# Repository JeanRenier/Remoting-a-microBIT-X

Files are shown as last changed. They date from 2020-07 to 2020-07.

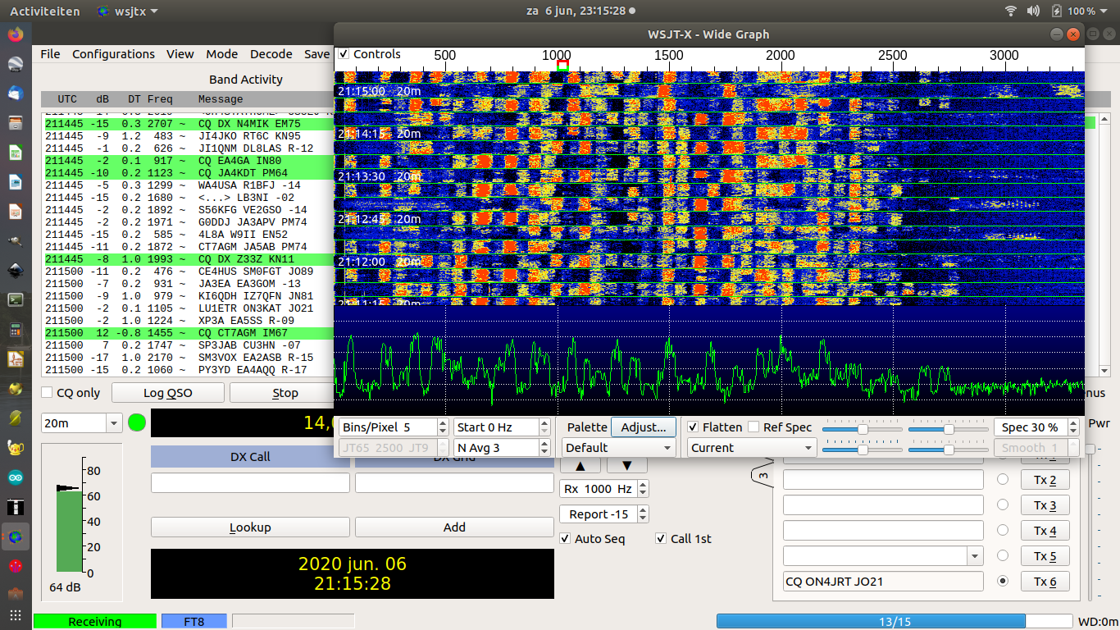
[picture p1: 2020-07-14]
pictures/WSJT-X_spectrum.png

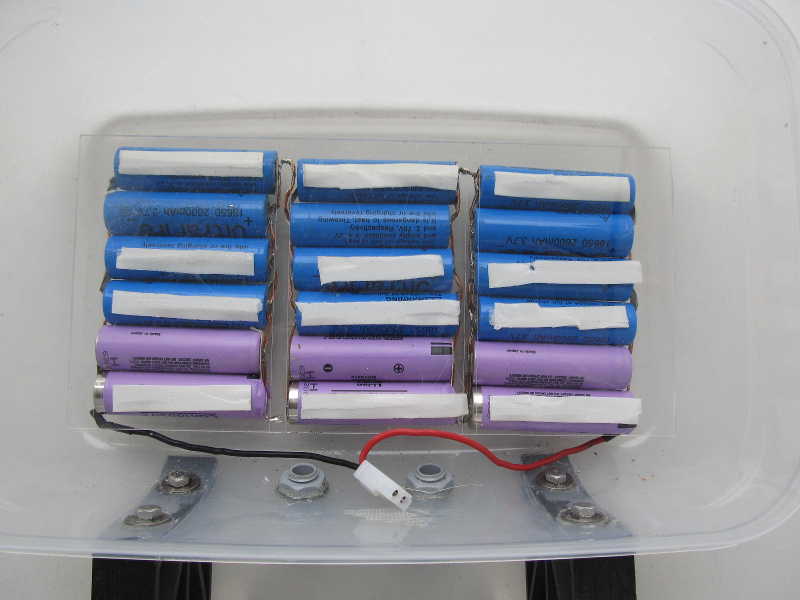
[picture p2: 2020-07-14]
pictures/remote_batteries.jpg

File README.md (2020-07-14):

**Introduction.**
 I became a licensed radio amateur when I retired some 10 years ago, my call is ON4JRT.
 Alas, moving to an apartment building a few years ago I lost the possibility to install a decent antenna. Even if I had the permission to install an antenna on the roof, the QRM generated by the building itself and the surrounding town would probably have made a clean reception almost impossible.
 A friend, who lives in the country side and to whom I am eternally grateful, came to my rescue and allowed me to install a remote transceiver and a modest antenna in his garden.

There are several remote transceiver projects described on the internet. Whilst they all are certainly more sophisticated and more performing than the rather simple system presented here, they are also much more demanding in resources (space, power, money, ...). I wanted a small stand alone system that would be self sustaining (save for an internet connection), not too conspicuous and not too expensive.
 Hence this project, which eventually was successful after a few trials. Its aim is to provide me with an remotely located transceiver for my own use, it is by no means a &quot;public&quot; transceiver available to other OM&#39;s.
 Like all engineering endeavor it consist of a series of choices and compromises, so don&#39;t shoot the pianist.

**The concept.**
 The remote transceiver system consists of several parts: A transceiver (obviously), a HF antenna, a battery, a small solar panel, a controller with a WiFi transceiver and a controller for the solar panel. Except for the HF antenna and the solar panel everything is enclosed in a small plastic housing of about 5 liter in volume.
 The remote transceiver communicates (i.e. the bidirectional data flows for sound, CAT and control) over the internet with a home device. This home device contains a simple user interface allowing some control over the remote device. Sound input and output is also available on this home device, as is a CAT interface. If I were a better PC/Posix software programmer I would probably gotten rid of the home device. Having the home device as a physical thing eases however the development (at least for me) while not adding too much to the cost.

**The transceiver.**
 After some search, I came across the µBIT-X (&quot;[https://www.hfsignals.com/index.php/ubitx/](https://www.hfsignals.com/index.php/ubitx/)&quot;) sold as a semi assembled kit developed by Ashhar Farhan (VU2ESE), now in its 6th version (I got the previous version for this project). It is a simple but rather well designed multi band HF QRP transceiver based on a double super architecture and bidirectional amplifiers (it uses almost all the building blocks for reception as well as for transmission). It is well documented, has a large fan club and most of the suggested improvements are officially endorsed.
 Coming out of the box, it needs to be calibrated and tuned (a bit). Apart from the CAT baud rate I didn&#39;t feel the need to modify anything. Obviously I didn&#39;t install the LCD or the rotary encoder (since nobody would look/touch at it), all control is performed via the CAT connection over the internet from the home device, and even then, very little of the CAT commands are really used.

**The µBIT-X controller, hardware.**

Beginning with the power supply: a DC/DC controller reduces the battery voltage to 4V, from there three linear regulators make the necessary 3.3V digital, 3.3V analog and 1.8V respectively.

An ESP32-WROOM module is the core of the controller, this awesome microprocessor includes the WiFi transceiver, performs all relevant IP chores and runs all the application software.
 It then interfaces a WM8731 codec by a I2Sbus for the digital sound and a I2Cbus for its control. This codec is a straight forward 16bit stereo ADC and DAC combination, it is programmed in this case for a sampling rate of 8kHz, yielding a sound bandwidth of 3400Hz, its dynamic range exceeds 90dB. The analog sound input and output from the codec goes through a set of isolating 600 Ohm 1:1 audio transformers and trimpots to the µBIT-X sound stages.
 The first UART of the ESP32 is exclusively used for programming and debugging.

The second UART interfaces the CAT of the µBIT-X including a PTT line. This interface is isolated with a set of optocouplers, limiting the baud rate to 4800. Note that the RD and TD lines of this interface actually bypass the USB-UART chip on the Arduino Nano board of the µBIT-X, luckily a series resistor was placed in the RD line of this Arduino Nano, hence no track cutting was nescessary.
 The third UART interfaces the Solar Controller board, it is also fit with optocouplers.
 At last the board is equipped with a PMOS switch capable of more than 2A to power the µBIT-X itself when required.

An additional small board comprising a simple tandem match type VSWR bridge is mounted directly on the antenna input/output of the µBIT-X. The detected forward and reflected signals are fed into the ADC inputs of the ESP32. With the help of some math and calibration, it gives a rather good indication of the HF power and VSWR during transmit.

**The µBIT-X controller, software.**

The software was build on the Arduino IDE (version 1.8.12) with the ESP32 plug in and libraries (version 1.0.4). It took several months of writing and careful testing, having the home device nearby was a great help.
 The software was not especially designed to be universal or portable. The several parameters like the IP addresses, URL&#39;s, etc. are &quot;hard coded&quot; in the software, no attempt was made for now to store them in a file structure or other form of non volatile memory. Hence there is no way to change them without recompiling the entire software.
 The software includes the interesting possibility of being updated &quot;over the air&quot;, i.e. via the WiFi as per the method recommended by Espressif. This was tested but not yet used, an additional port forwarding on the remote router is needed tor this.

The setup part of the software starts with the initialization of the several internal and external peripherals. After that a WiFi connection with one of the friendly WiFi AP&#39;s is established, that done the µBIT-X Controller will synchronizes with an NTP server, checking in at a DDNS server and send a short e-mail as a sign of live. Once the setup is done two endless loops will take care of business until powered off.
 One of the loops is dedicated to the audio interface, seeing to it that the digital sound samples flow in and out the codec through the I2Sbus at a constant rate of 8kHz.
 The other loop will handle the incoming and outgoing UDP packets. Outgoing packets are sent only when incoming UDP packets are present, i.e. only during a connection between the µBIT-X controller and the home device.

The data in each packet is split into three separate flows, the biggest one being the sound, a smaller one for the CAT going directly to/from the µBIT-X and the last one for the housekeeping of the µBIT-X Controller itself and the Solar Controller.

During a connection there is a UDP flow of 25 packets per second in each direction. Each packet has 660 bytes is build as follows:
 - bytes 0...639 : 320 16bit sound samples, 8000 samples/s

- byte 640...641 : packet count and control byte, including the PTT bit

- byte 642...646 : CAT bytes, max 5 to/from the µBIT-X

- byte 647...659 : CTL bytes, max 13 to/from the Solar Controller
 The sound samples of the incoming packets are stored in a circular buffer of 1s. Currently there is no provision made to cope with lost packets, if the circular buffer runs out, silence is send to the codec until its filled again for at least a quarter. Packet loss has not been a problem so far, typically no more than one packet per thousand gets lost.
 Likewise, differential drift of the sample clock, the 8kHz sampling rates at send and receive sides are not exactly equal, is simply ignored, though I may change this in future.

A few words about the IP addressing. In normal circumstances both the home device and µBIT-X Controller are connected to their respective WiFI AP&#39;s that are typically part of a modem router devices provided by Internet Access operators. The IP addresses of these devices are variable over time as the operators see fit. Hence the use of a DDNS server, the free service &quot;www.duckdns.org&quot; was chosen here. Both sides of the link are then known by their URL&#39;s i.e. &quot;remote\_name.duckdns.org&quot; and &quot;home\_name.duckdns.org&quot; respectively.
 That is one problem solved, still the packets need to pass the modem routers and be directed to the devices. This is done by setting a port forwarding for the appropriate port number in the modem router at both sides.
 Most modem routers have the tendency to assign a new IP address to the devices each time they connect. In order to avoid that, fixed IP addresses are organized for each device, hence the port forwarding can be set once and for all. The fixed IP addresses should carefully be chosen in order not to disturb the other IP stations on the local area (i.e. choosing one outside of the DHCP range of the modem).
 A more elegant solution to avoid the fixed IP addresses and the port forwarding settings in the modem routers would be the use of the UPnP method. There are good libraries for this method, e.g. &quot;[https://github.com/ofekp/TinyUPnP](https://github.com/ofekp/TinyUPnP)&quot;, with which I played a bit. It probably works but I was not able to test it due to some issues with my own modem router, so I stick with the port forwarding and fixed IP addresses for now.

**The solar panel controller.**
 The µBIT-X controller board (see further) takes about 38mA during normal operation (the µBIT-X itself being turned off), this was deemed too much to have it continuously running. Hence a scheme was preferred where the remote transceiver would become available through the internet for a few hours everyday at some predetermined time, e.g. from 8 o&#39;clock in the evening till midnight. This scheme works for me, though it may not be the case for everybody.

For this alarm clock/timer function a 24 hour real time clock was implemented in software. The power on time, the power off time and also the current time are settable remotely once a connection with the home device has been made.
 Besides of the above function the solar controller board is also supervising the charge of the battery. This function is kept extremely simple: when the battery voltage rises higher than 12.3V a PMOS switch is opened prohibiting the further charging of the battery from the solar panel. Likewise, if the battery voltage falls below 9.3V an other PMOS switch will cut the load (i.e. the rest of the system) in order to protect the battery from deep discharge damage. As the solar panel itself behaves very much like a current source and yields at most about 0.6A, no attempt is made to limit the charging current, it remains well below the maximum charging current of the Li-Ion battery.

This little board was designed some four years ago, it is built around the ATtiny84 chip and is furthermore connected via a serial port to the µBIT-X controller for housekeeping, such as the above mentioned timings, the battery voltage and the temperature inside the box. It takes a mere 3mA (continuously) from the battery.

**The battery.**
 Nothing very much is to be said about the battery, it is just an assembly of 18 Li-Ion cells of the 18650 format, 6 in parallel and 3 in series, yielding a nominal voltage of 11.1V and a capacity of 13Ah.
 Nothing is foreseen to perform load balancing, as is typical for Li-Ion batteries. After three &quot;campaigns&quot; in the field of 6 months each, no significant voltage drift was noted on the individual cell groups. This may be due to the rather gentle use of this battery, it is used mostly when nearly full (close to 12V), charged with no more than 0.6A (limited by the solar panel) and discharged with no more than 1.5A (µBIT-X transmitting) and the latter only during short periods.
 There is some concern about the temperature range of the the Li-Ion batteries: 0...40°C, which can easily be overreached during cold winters and hot summers. A thin Aluminum sheet is foreseen behind the south side of the housing to provide some shade for it.

**The housing.**
 A regular fridge/kitchen type PE box with a watertight lid of roughly 300\*200\*100mm (ca. 5 liter) was chosen as a housing for the entire remote system. An unorthodox choice, but there were never any problems with rain or weather during the accumulated 18 plus months of outdoor live so far.
 The box is traversed by two cables, one for the HF antenna (RG 58 coax) and one for the solar panel (round flexible twin electricity cable), both foreseen with pressure glands.
 Two &quot;feet&quot; are furthermore foreseen to enable the box to stand upright with its 200mm side vertical.
 The rear part of the box is reserved for the battery, the front part for the WiFi antenna (a double biquad), the in between space is filled with the µBIT-X, the µBIT-X controller and the solar controller. It was a bit of a shoe horn exercise, but nobody did complain...
 A few pouches of silica gel drying agent were inserted before the final closure of the lid.

**The solar panel.**
 The solar panel looks a bit like a picture frame, a slim Aluminum frame holds two sheets of glass between which 35 poly-crystalline photo voltaic cells are mounted in series. Its dimension is 330\*290mm. It is rated 10W by the manufacturer, if exposed perpendicular to the sun during a clear day it would yield about 17.5V (open circuit) and 0.6A (short circuit). It is installed in the garden more or less in an open space, near to the remote transceiver box, facing south and tilted at 45°.
 Theoretically, considering the statistics for my part of the world, it would yield 3.5Ah on an average summer day and 0.7Ah on an average winter day. Plenty to play with, at least during summer.

**The antenna.**
 Discretion is the keyword here, a simple 20m band wire dipole was installed horizontally between the trees in the garden. For practical reasons the resonant feed line design was chosen here, the height above the ground is about 3.5m. Alas, too low to make it a good DX antenna, but then it was that or nothing. The antenna is entirily made of RG58 cable, a nylon rope runs along with it for improved strength.
 The antenna impedance was measured and a small fixed LC circuit was installed in the remote transceiver box as an antenna tuner of sorts to ensure that the VSWR remains below 1.5.
 It was noted that the VSWR varies from 1.2 to 1.5 depending the weather.

**The home device, hardware.**
 The hardware of the little home device is very similar as that of the µBIT-X Controller. The sound is connected to the audio input/output of a PC with a 3.5mm audio jack. The incoming sound is also diverted to a small (30mm) loudspeaker to monitor the received signal.
 Note that the sound levels are kept intentionally high (i.e. around 1Veff), this in order to maximize the S/N ratio. The sound input/output towards the PC must hence be set accordingly (maximum for the output and almost nil for the input).
 The second UART is led through a UART-USB chip and is used for the CAT. The USB connection is also used for powering the home device. Further peripherals are a small OLED display (128\*64 pixels) connected to the I2Cbus (to monitor some vital parameters of the remote), a rotary encoder (to change the frequency), a potentiometer (speaker volume) and a toggle switch (to start/stop the connection with the remote).

**The home device, software.**
 The software of the little home device is also very similar to that of the µBIT-X Controller. No NTP synchronization or e-mail sending, instead the OLED display is configured during setup.
 During looping, the sending of packets is controlled by the toggle switch. Control and CAT messages coming from the remote are parsed and put on the OLED display: current frequency and mode, HF power out, VSWR, received packet count (at both ends), RSSI of the WiFi link (at both ends), battery voltage and temperature inside the housing.

A few words about the handling of the CAT messages. By design the µBIT-X emulates (at least the meaningful part of) the CAT messages of the Yeasu FT817/FT857 transceiver. This works well when the µBIT-X is connected directly to a PC, I could however not make it work when connected to through the chain of devices and the internet, most probably a question of delay.
 The following scheme was then implemented: The home device emulates in itself the above transceivers, responding immediately to satisfy the application on the PC. If something is changed (in practice the frequency or the mode) the corresponding message is send over the internet to the remote µBIT-X controller and to the µBIT-X itself. Any response of the latter is returned over the internet to the user interface of the home device.
 This scheme works well with Fldigi, however not at all with WSJT-X for reasons I have yet to understand. As for the PTT, three methods are simply used in parallel: the DTR method, the CAT method and the VOX method (implemented in software).

**Construction notes.**
The PCB&#39;s were designed with KiCad (version 5.1.6) in the form of a two layer board with generous ground planes. Most of the components are SMD though still solderable by hand.
 The board assembled in one panel were manufactured by jlcpcb.com, they offer an excellent and fast service. Care was taken to get all the boards within an area of 100\*100mm, their more or less permanent prototype discount offer.
 Most of the components were purchased at &quot;www.tme.eu&quot; and &quot;[www.r](http://www.reichelt.com/)[eichelt.com](http://www.reichelt.com/)&quot;. The more exotic components (OLED display, audio transformers, ESP32-WROOM module, WM8731A, …) were purchased at &quot;[www.aliexpress.com](http://www.aliexpress.com/)&quot;, the stuff is on the road for about 6 weeks, but the price is unbeatable.

In order to load the software into the ESP32 with the Arduino IDE, a small UART-USB module should be connected to the first UART (debug, only the RD, TD and GND lines), the boot strap should be shorted and the reset button should be pressed.
 The Solar Controlled was designed several years earlier, its software was made with AVR Studio 4. Alas, there is no Arduino IDE support for the ATtiny84.
 Finally, the housing of the home device was 3D-printed (a little box of 100\*50\*30mm), it was designed with OpenScad.

**Performance of the system as a whole.**

I am active only on the 20m band for now, the antenna being strictly monoband, and then mostly in the popular FT8 mode. With the 6...7W of output power it seems that I suffer some 10...15dB disadvantage versus other stations (difference of their S/N report versus my S/N report). This is probably more an issue of the QRP nature of the µBIT-X than the fact it is connected via the internet.
 The additional time delay due to digitization and buffering of the sound does not seem to have a significant effect, it is about 0.7s.

An other concern is the lack of cooling in the rather hermetic non metallic housing. When busy for one hour atempting QSO&#39;s in FT8, the temperature inside the housing will rise by typically 5°C. Not too bad, but then it says little about the temperature of the power FET&#39;s of the PA. Initial tests however indicated that their rather small radiators didn&#39;t became too hot even after several minutes of transmitting.

Battery drain of the remote part:
 - Solar Controller: 3mA (continuous)
 - µBIT-X Controller: 38mA (when awake)

- µBIT-X receiving: 175mA (when connected with the home device)
 - µBIT-X transmitting: 1125mA (when transmitting a single tone at 6W)

**Further improvements and other considerations.**
 Since the µBiT-X is multi band, as a further evolution of this project, I intend to have a multi band antenna (at least adding the 40m band) and some form of switchable/variable antenna tuner.

Some trick to capture the speed of rotation of the rotary encoder on the home device and to vary the frequency step accordingly would be useful. Now each step is strictly 100Hz, which is rather inconvenient. Making WSJT-X&#39;s CAT work with the home device would also be nice.
 Currently there is no provision made as for internet security, i.o.w. anybody with the right format of UDP packets can access the remote device and use it (he/she has still to know the relevant URL of course). Some scheme with an encrypted signature (e.g. HMAC style) inside each packet authenticating the home device would be an improvement.
 Though the current design is intended for the use with digimodes, it can easily be adapted for voice operations. Adding a microphone amplifier and a PTT switch input would then be required.

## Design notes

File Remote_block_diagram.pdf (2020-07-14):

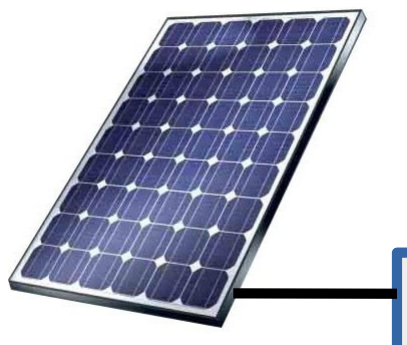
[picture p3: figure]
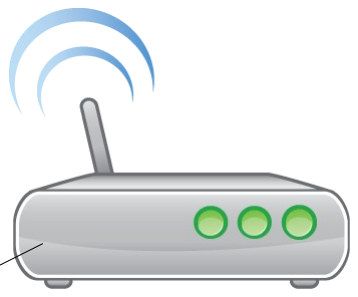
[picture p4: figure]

Remote
unit

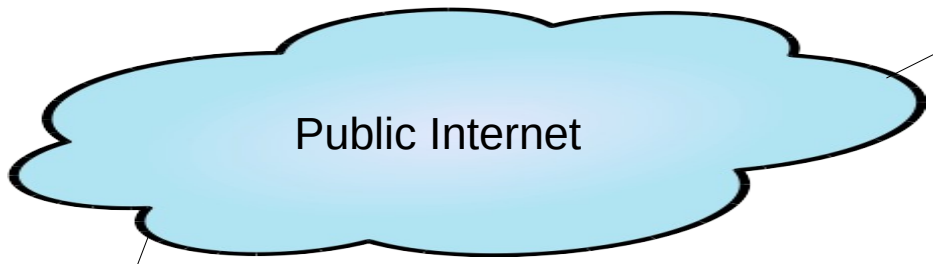
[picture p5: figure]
Public Internet
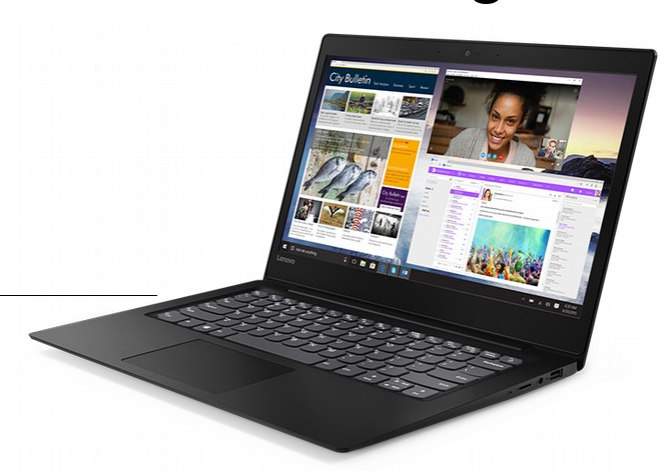
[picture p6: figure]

Local
unit

Remote WiFi LAN

Local WiFi LAN

10Wp Solar panel

20m RFD antenna

PC with FLdigi, WSJT, ...

## λ Remote unit (block diagram)

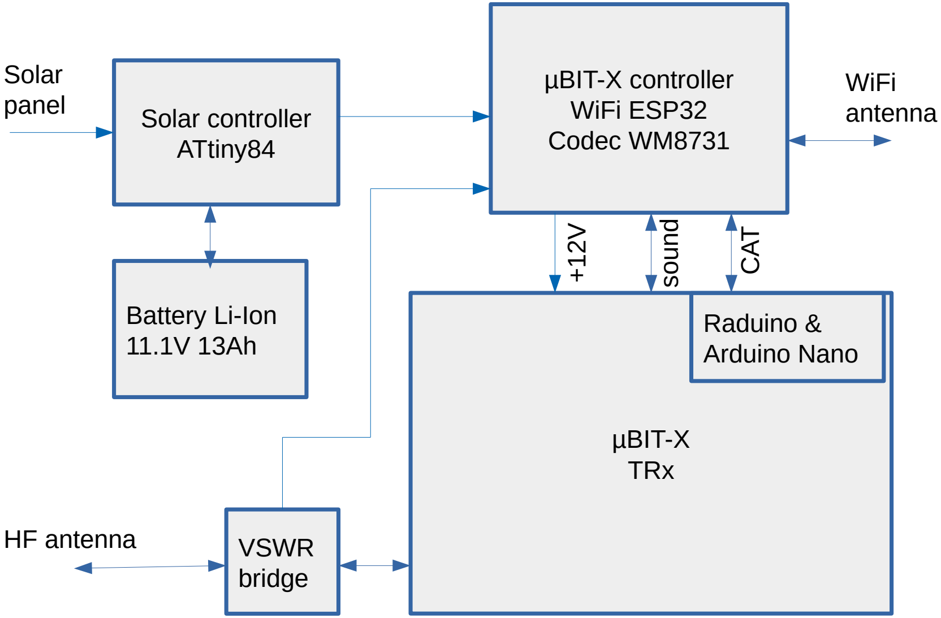
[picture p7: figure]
Solar controller ATtiny84; µBIT-X controller WiFi ESP32 Codec WM8731; Battery Li-Ion 11.1V 13Ah; µBIT-X TRx; VSWR bridge; Solar panel; WiFi antenna; HF antenna; Raduino & Arduino Nano

## λ Local unit (block diagram)

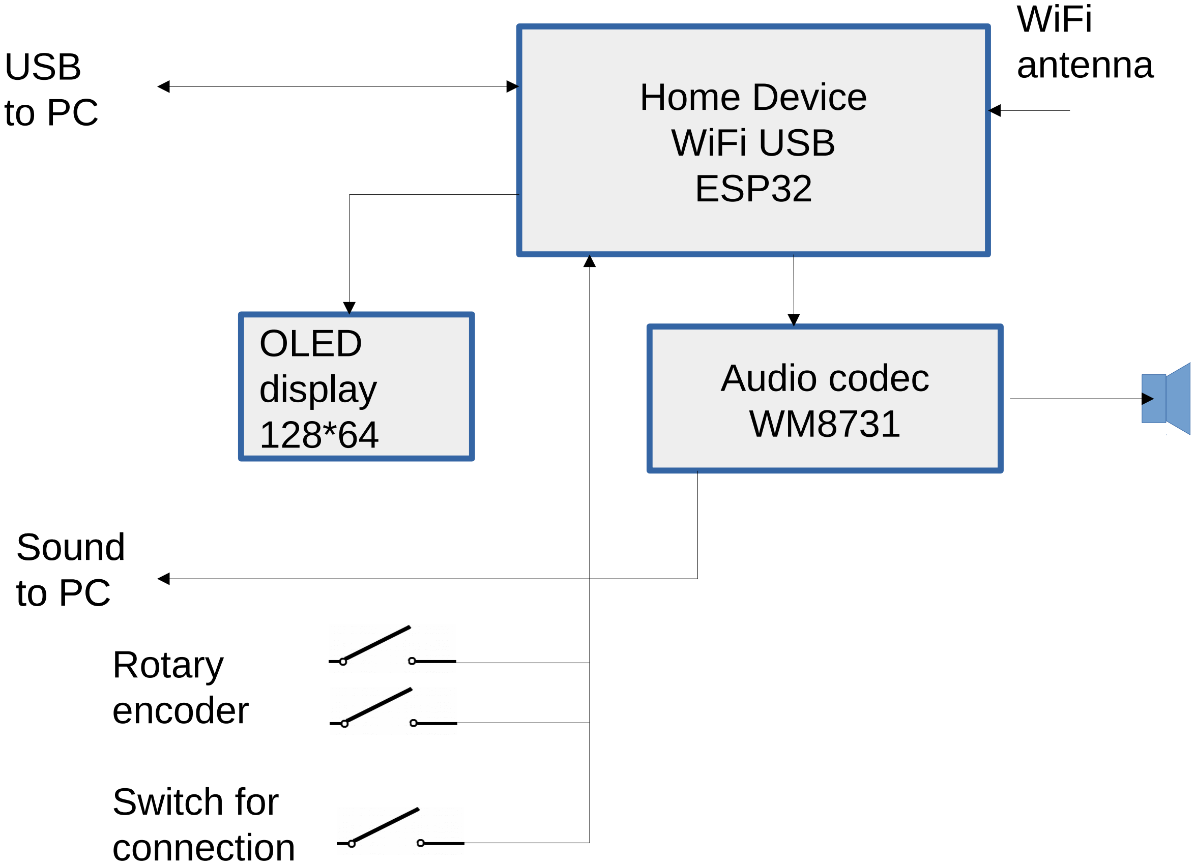
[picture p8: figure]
Home Device WiFi USB ESP32; Audio codec WM8731; WiFi antenna; OLED display 128*64; Sound to PC; USB to PC; Rotary encoder; Switch for connection

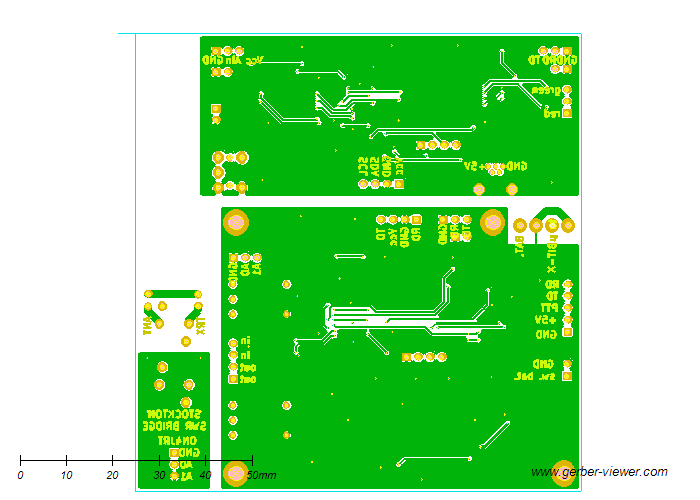
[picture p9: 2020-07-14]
hardware/remote3_layout_bot.png

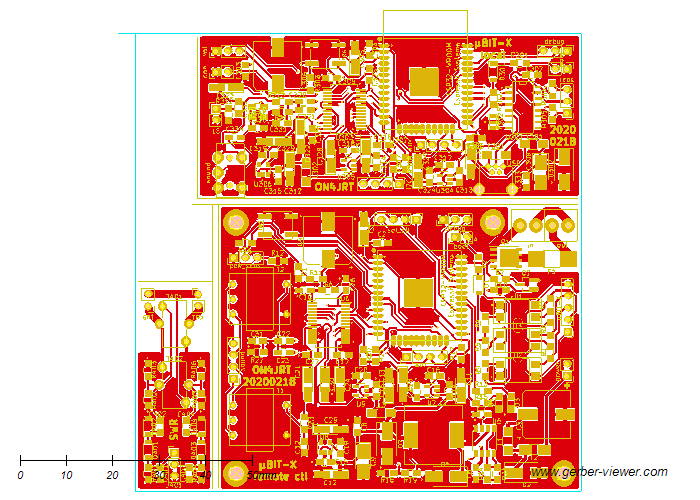
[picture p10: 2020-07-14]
hardware/remote3_layout_top.png

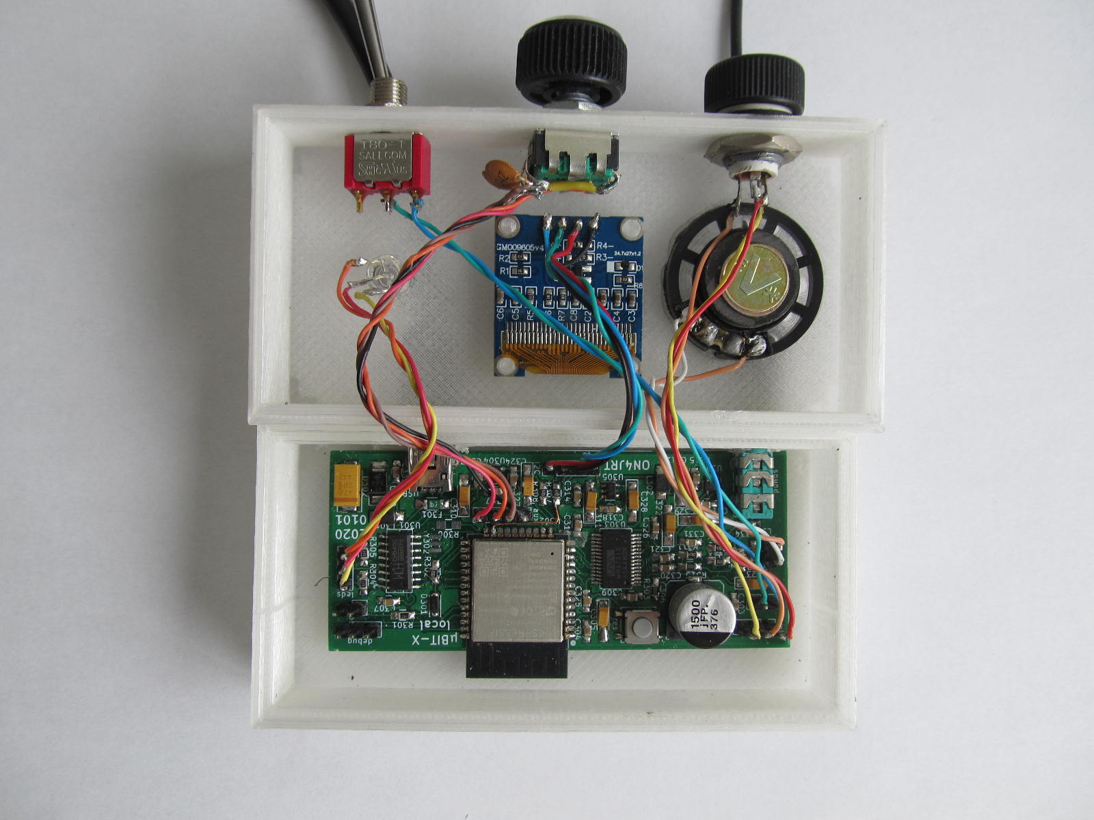
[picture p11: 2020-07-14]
pictures/home_interns.jpg

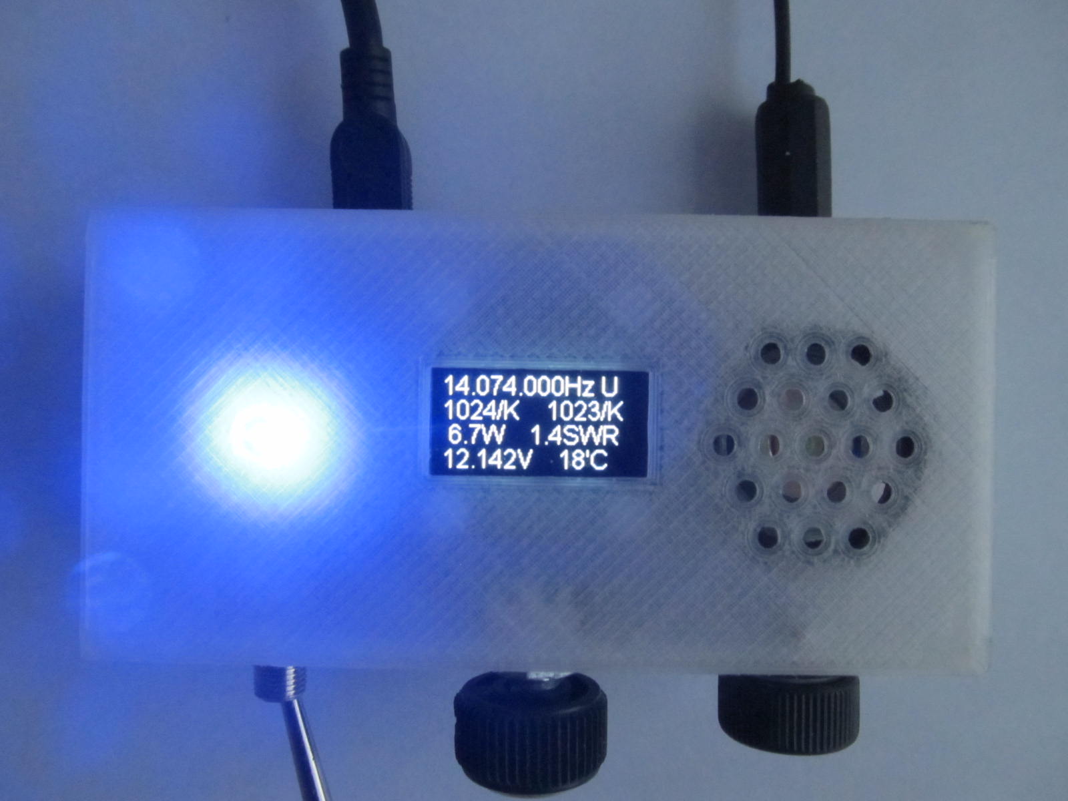
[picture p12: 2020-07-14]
pictures/home_transmitting.jpg

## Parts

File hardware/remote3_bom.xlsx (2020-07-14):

Id | Designator | Package | Quantity | Designation | Supplier and ref
Semiconductors
1 | U302 | ESP32-WROOM | 1 | ESP32-WROOM 32D with PCB antenna | AliExpress
2 | U4 | ESP32-WROOM | 1 | ESP32-WROOM 32U with IPEX connector | AliExpress
3 | U1,U2,U3 | DIP-4_W7.62mm_SMDSocket_SmallPads | 3 | SFH1690AT
4 | U5 | SOIC-8_3.9x4.9mm_Pitch1.27mm | 1 | MC34063
5 | U6,U303 | SSOP-28_5.3x10.2mm_Pitch0.65mm | 2 | WM8731 | AliExpress
6 | U7,U9,U304,U306 | SOT-23-5 | 4 | tc1185-3.3V
7 | U8,U305 | SOT-23-5 | 2 | tc1185-1.8V
8 | U301 | SO-16-N | 1 | CH340G | AliExpress
9 | Q1 | PowerPAK_SO-8_Single | 1 | AO4407A
10 | Q2 | SOT-23_Handsoldering | 1 | BSS138
11 | D3 | LED_0805_HandSoldering | 1 | green
12 | D4 | LED_0805_HandSoldering | 1 | red
13 | D1,D301 | D_SOD-123 | 2 | 1N4148
14 | D2 | D_SMB_Handsoldering | 1 | 15V transil
15 | D7,D302 | D_SMB_Handsoldering | 2 | 5.1V transil
16 | D5,D401,D402,D403,D404 | D_SOD-123 | 5 | BAT85
Inductors
17 | L1,L3,L301,L302 | L_1206_HandSoldering | 4 | 10u
18 | L2 | L_12x12mm_h8mm | 1 | 100u
19 | T401,T402 | L_Toroid_Vertical_L10.0mm_W5.0mm_P5.08mm | 2 | FT-37-43
Capacitors
20 | C7,C18,C19,C20,C31,C32,C317,C318,C319,C330,C331,C332 | C_0805_HandSoldering | 12 | 470p
21 | C1,C303 | C_0805_HandSoldering | 2 | 10n
22 | C2,C6,C8,C10,C14,C15,C16,C17,C22,C23,C25,C26,C27,C304,C307,C309,C313,C314,C315,C316,C320,C321,C324,C325,C326,C401,C402,C333,C334,C403,C404 | C_0805_HandSoldering | 31 | 100n
23 | C3,C305 | CP_Tantalum_Case-A_EIA-3216-18_Hand | 2 | 1.5u
24 | C11,C12,C13,C21,C24,C28,C29,C30,C310,C311,C312,C322,C327,C328,C329 | CP_Tantalum_Case-A_EIA-3216-18_Hand | 15 | 10u
25 | C9,C308,C323 | CP_Tantalum_Case-B_EIA-3528-21_Hand | 3 | 100u
26 | C5 | CP_Elec_10x10 | 1 | 470u, 16V
27 | C4,C306 | CP_Elec_10x10 | 2 | 1500u, 6V
Resistors
28 | R14,R24 | R_0805_HandSoldering | 2 | 1
29 | R312 | R_0805_HandSoldering | 1 | 10
30 | R23 | R_0805_HandSoldering | 1 | 33
31 | R402,R403,R405,R406 | R_0805_HandSoldering | 4 | 100
32 | R2,R5,R9,R13,R15,R301,R304,R305 | R_0805_HandSoldering | 8 | 330
33 | R3 | R_0805_HandSoldering | 1 | 680
34 | R4 | R_0805_HandSoldering | 1 | 3.3k
35 | R1,R8,R20,R21,R307,R308,R309,R313 | R_0805_HandSoldering | 8 | 4.7k
36 | R6,R7,R10,R11,R17,R18,R302,R303,R306,R401,R404 | R_0805_HandSoldering | 11 | 10k
37 | R19 | R_0805_HandSoldering | 1 | 22k
38 | R12,R16 | R_0805_HandSoldering | 2 | 100k
39 | R22,R310,R311 | R_0805_HandSoldering | 3 | 51k
Other
40 | Y302 | Resonator_SMD-3pin_7.2x3.0mm | 1 | 12MHz | AliExpress
41 | T2,T1 | Transformer 13.5*13.4*9.1mm | 2 | 1:1, 600Ohm, 1.6H, | AliExpress
42 | push button | SW_SPST_EVPBF | 2 | reset
43 | F2,F301 | R_1206_HandSoldering | 2 | 0.35A
44 | F1 | R_1812_HandSoldering | 1 | 2.6A
Connectors
45 | USB_B_mini | USB mini_B THT, angled | 1 | JST: UB-M5BR-DM14-4D
46 | sound | PJ320E_3.5mm_Jack | 1 | salvage
47 | in,out | TerminalBlock_bornier-2_P5.08mm | 2
48 | in | TerminalBlock_bornier-2_P5.08mm | 1
49 | diverse | Pin_Header_Straight_1x10_Pitch2.54mm | 5 | breakable
Off board
50 | potentiometer | 6mm shaft, hole mount, 10k linear | 1 | plus dito knob
51 | rotary encoder | 6mm shaft, incl. push switch | 1 | plus dito knob | AliExpress
52 | loadspeaker | Miniature: 30mm diam., 32 Ohm | 1 |  | AliExpress
53 | OLED display | 0,96” diagonal, 128*64 pixels, white/blue, IC2 interface | 1 |  | AliExpress
54 | toggle switch | 6mm shaft, hole mount, SPST | 1
55 | leds | 5mm led, common anode | 1 | bicolor led (red/green)
56 | diverse | Pin_Header_Female Straight_1x10_Pitch2.54mm | 5

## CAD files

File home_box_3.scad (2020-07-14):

// box for remote HF mk3 home device

module grid() {
    for (i = [0:4]) {
        translate([i*5,0,0])cylinder(d=3, h= 4, $fn=90);
    }
    for (i = [0:3]) {
        translate([2.5 + (i*5),5,0])cylinder(d=3, h= 4, $fn=90);
        translate([2.5 + (i*5),-5,0])cylinder(d=3, h= 4, $fn=90);
    }
    for (i = [0:2]) {
        translate([5 + (i*5),10,0])cylinder(d=3, h= 4, $fn=90);
        translate([5 + (i*5),-10,0])cylinder(d=3, h= 4, $fn=90);
    }
}
// bottom part
    translate([0,55,0])difference() {
        union() {
        // bottom
        translate([-50,-25,0])cube([100,50,1.5]);
        // walls & rims
        translate([-50,-25,0])cube([3,50,15]);
        translate([-50,-25,15])cube([1.4,50,2.5]);
        translate([47,-25,0])cube([3,50,15]);
        translate([48.6,-25,15])cube([1.4,50,2.5]);
        translate([-50,-25,0])cube([100,3,15]);
        translate([-50,-25,15])cube([100,1.4,2.5]);
        translate([-50,22,0])cube([100,3,15]);
        translate([-50,23.6,15])cube([100,1.4,2.5]);
    }
      // usb
      translate([27,-26,4])cube([10,6,5]);
      // sound
      translate([-27,-21,7])rotate([90,0,0])cylinder(d=6, h=6, $fn=90);
}
     
// top part
difference () {
    union() {
      // bottom
      translate([-50,-25,0])cube([100,50,1.5]);
      // walls & rims
      translate([-50,-25,0])cube([3,50,15]);
      translate([-48.4,-23.4,15])cube([1.4,46.8,2.5]);
      translate([47,-25,0])cube([3,50,15]);
      translate([47,-23.4,15])cube([1.4,46.8,2.5]);
      translate([-50,-25,0])cube([100,3,15]);
      translate([-47,-23.4,15])cube([94,1.4,2.5]);
      translate([-50,22,0])cube([100,3,15]);
      translate([-47,22,15])cube([94,1.4,2.5]);
      // OLED display attachments
      translate([10,15,0])cylinder(d=2.6, h= 7.5, $fn=90);
      translate([-10,15,0])cylinder(d=2.6, h= 7.5, $fn=90);
      translate([10,-8,0])cylinder(d=2.6, h= 7.5, $fn=90);
      translate([-10,-8,0])cylinder(d=2.6, h= 7.5, $fn=90); 
      translate([10,15,0])cylinder(d=4.8, h= 4.5, $fn=90);
      translate([-10,15,0])cylinder(d=4.8, h= 4.5, $fn=90);
      translate([10,-8,0])cylinder(d=4.8, h= 4.5, $fn=90);
      translate([-10,-8,0])cylinder(d=4.8, h= 4.5, $fn=90);  
    }    
     // OLED display
    translate([-12,-4,-1])cube([24,12,4]);      
    // loudspeaker
    translate([-40,0,-1])grid();
    // LED
    translate([30,0,-1])cylinder(d=5, h= 4, $fn=90);
    // connect swirch
    translate([30,-21,8.5])rotate([90,0,0])cylinder(d=6.2, h= 6, $fn=90);
    // connect switch
    translate([0,-21,8.5])rotate([90,0,0])cylinder(d=7, h= 6, $fn=90);  
    // volume potentiometer
    translate([-30,-21,8.5])rotate([90,0,0])cylinder(d=10.2, h= 6, $fn=90);
  }
 
  // adesion helpers (optional)
  translate([50,25,0])cylinder(d=8, h=1, $fn=60);
  translate([50,-25,0])cylinder(d=8, h=1, $fn=60);
  translate([-50,25,0])cylinder(d=8, h=1, $fn=60);
  translate([-50,-25,0])cylinder(d=8, h=1, $fn=60); 
  translate([0,55,0]) {
  translate([50,25,0])cylinder(d=8, h=1, $fn=60);
  translate([50,-25,0])cylinder(d=8, h=1, $fn=60);
  translate([-50,25,0])cylinder(d=8, h=1, $fn=60);
  translate([-50,-25,0])cylinder(d=8, h=1, $fn=60); } 

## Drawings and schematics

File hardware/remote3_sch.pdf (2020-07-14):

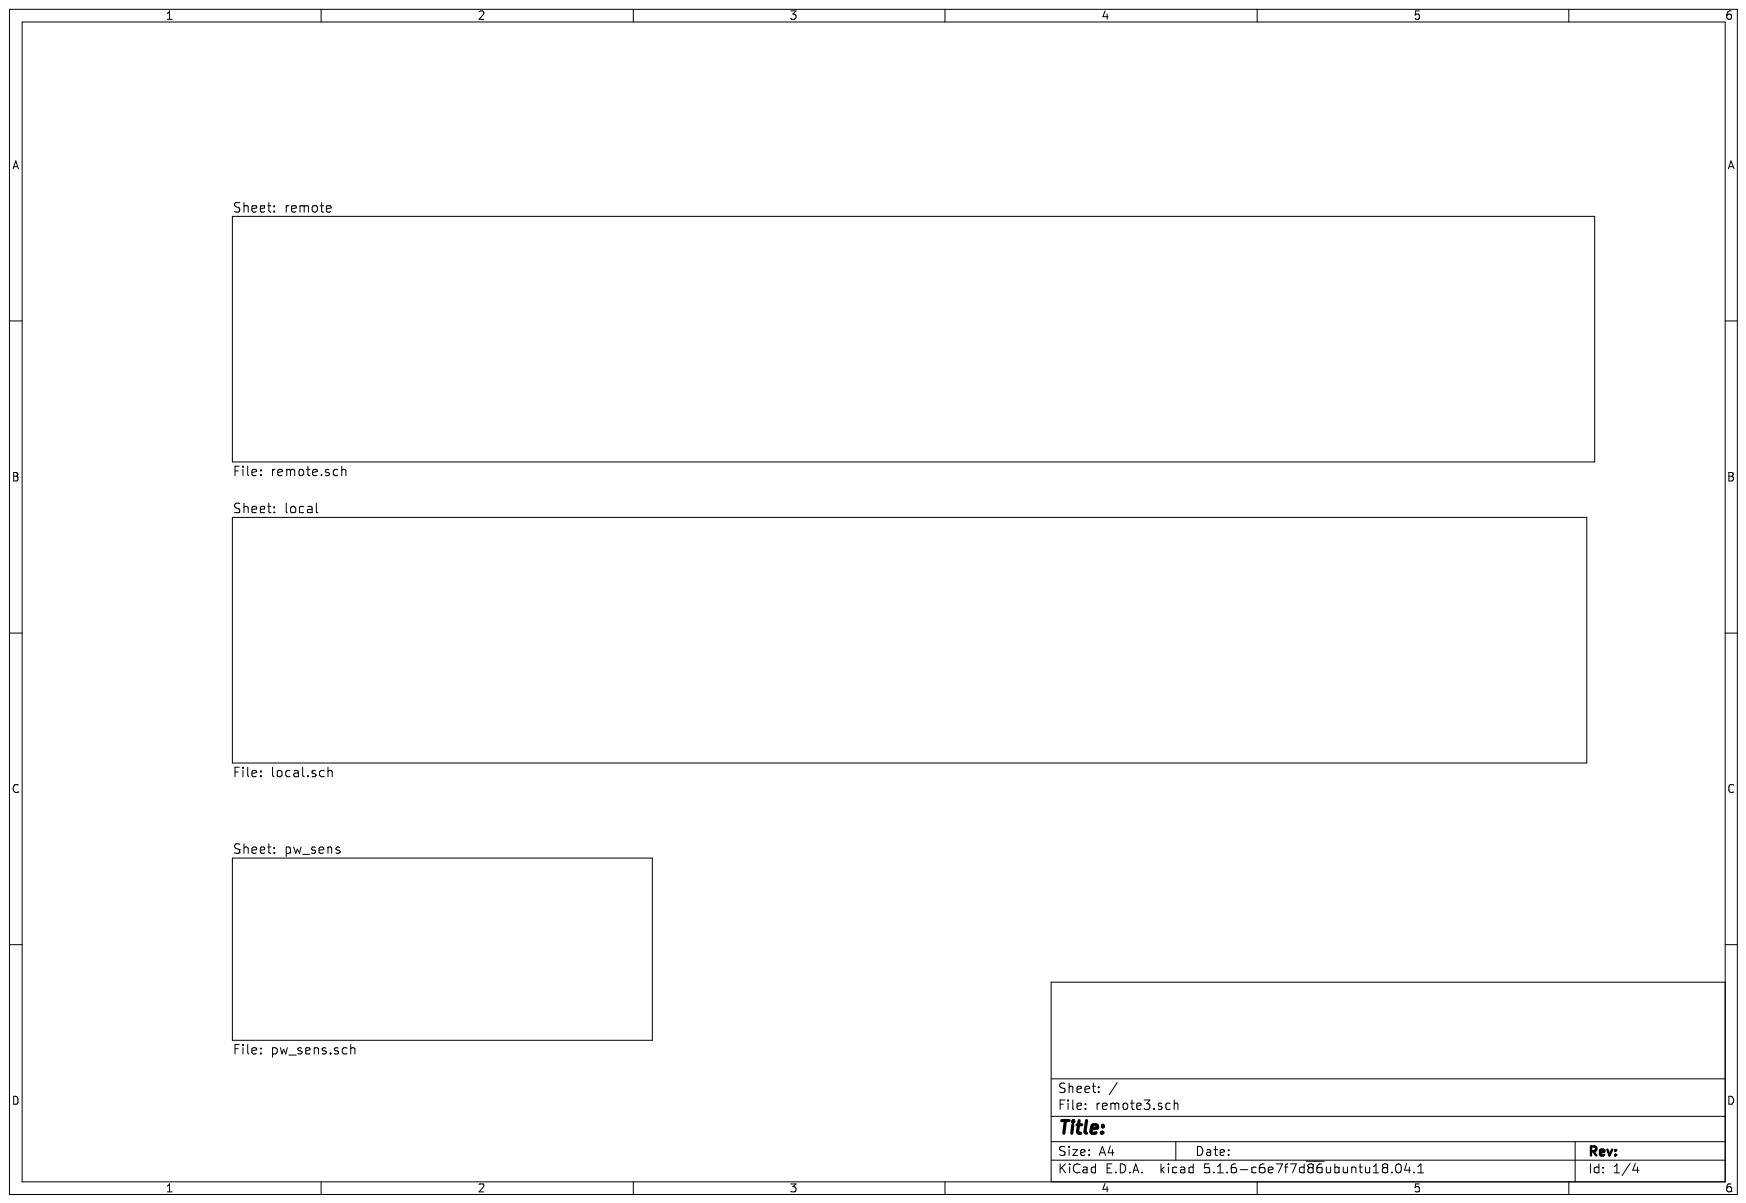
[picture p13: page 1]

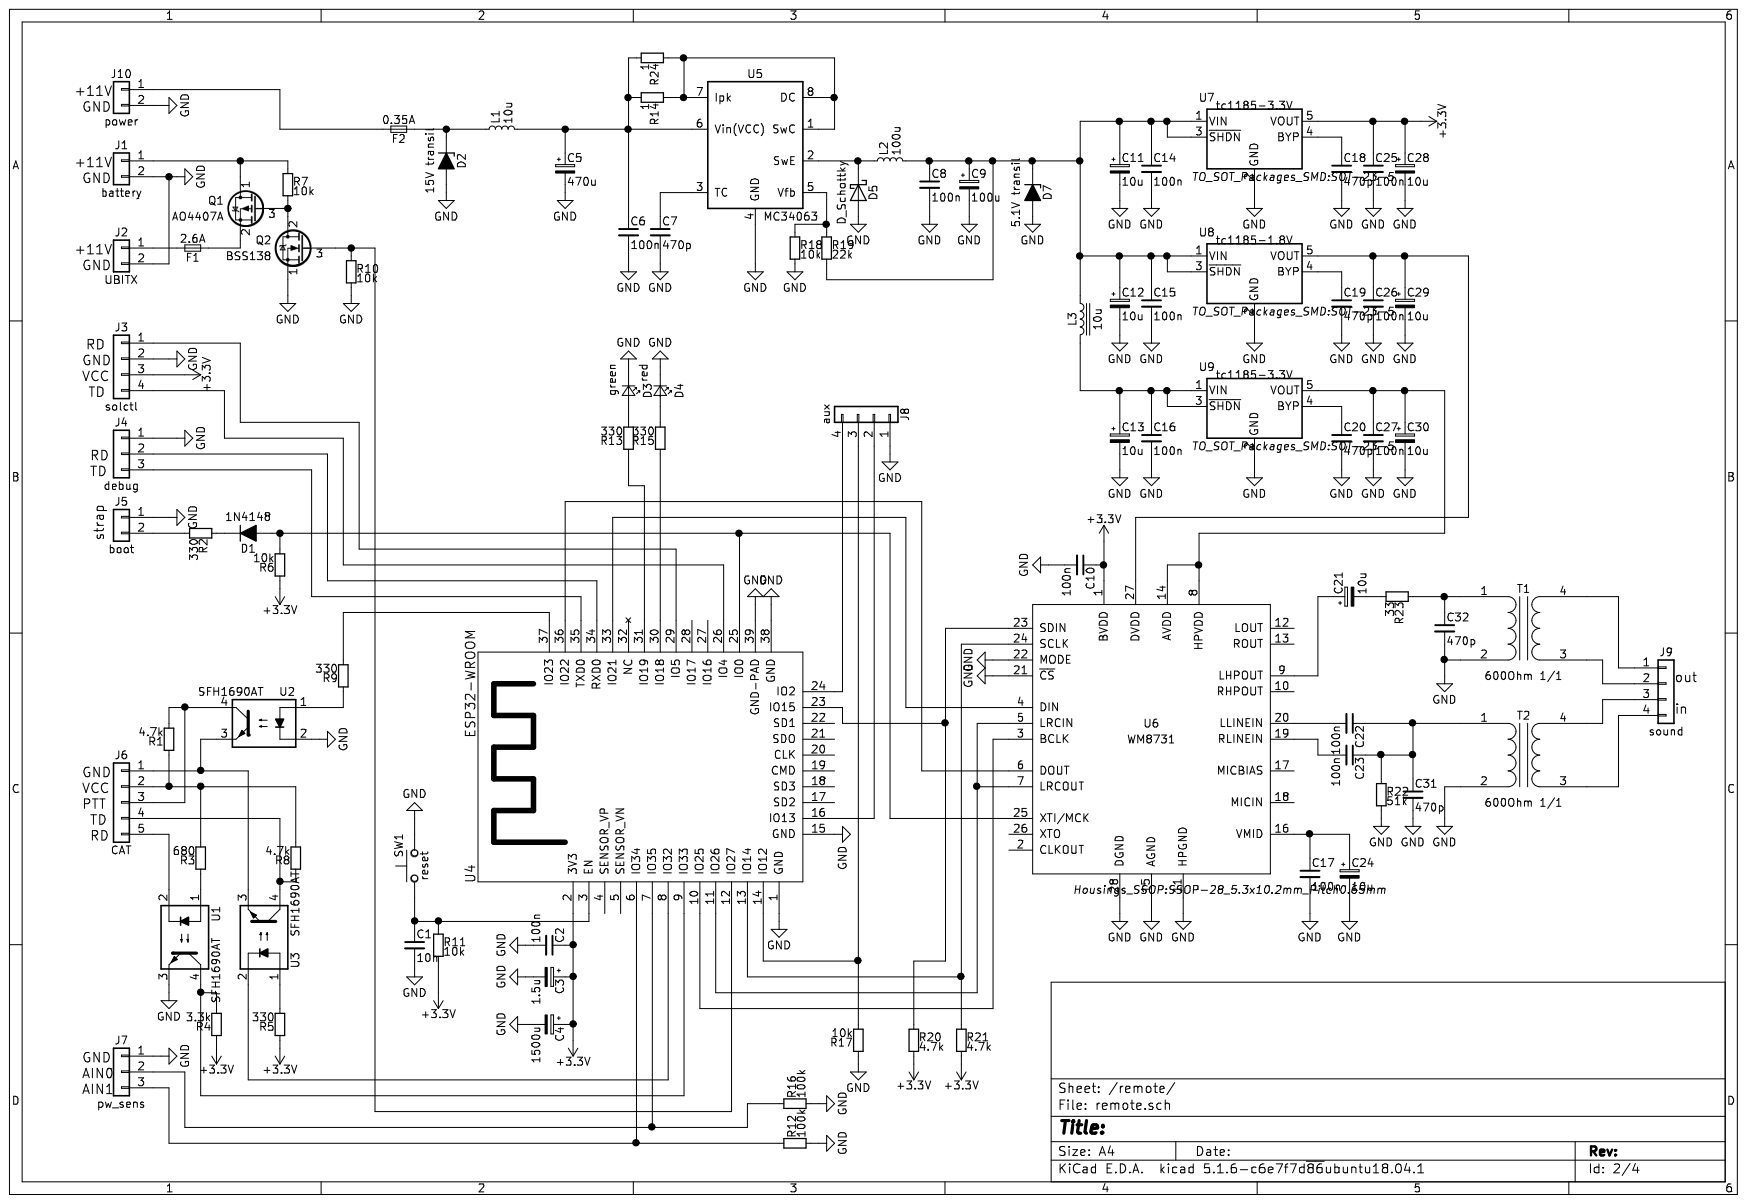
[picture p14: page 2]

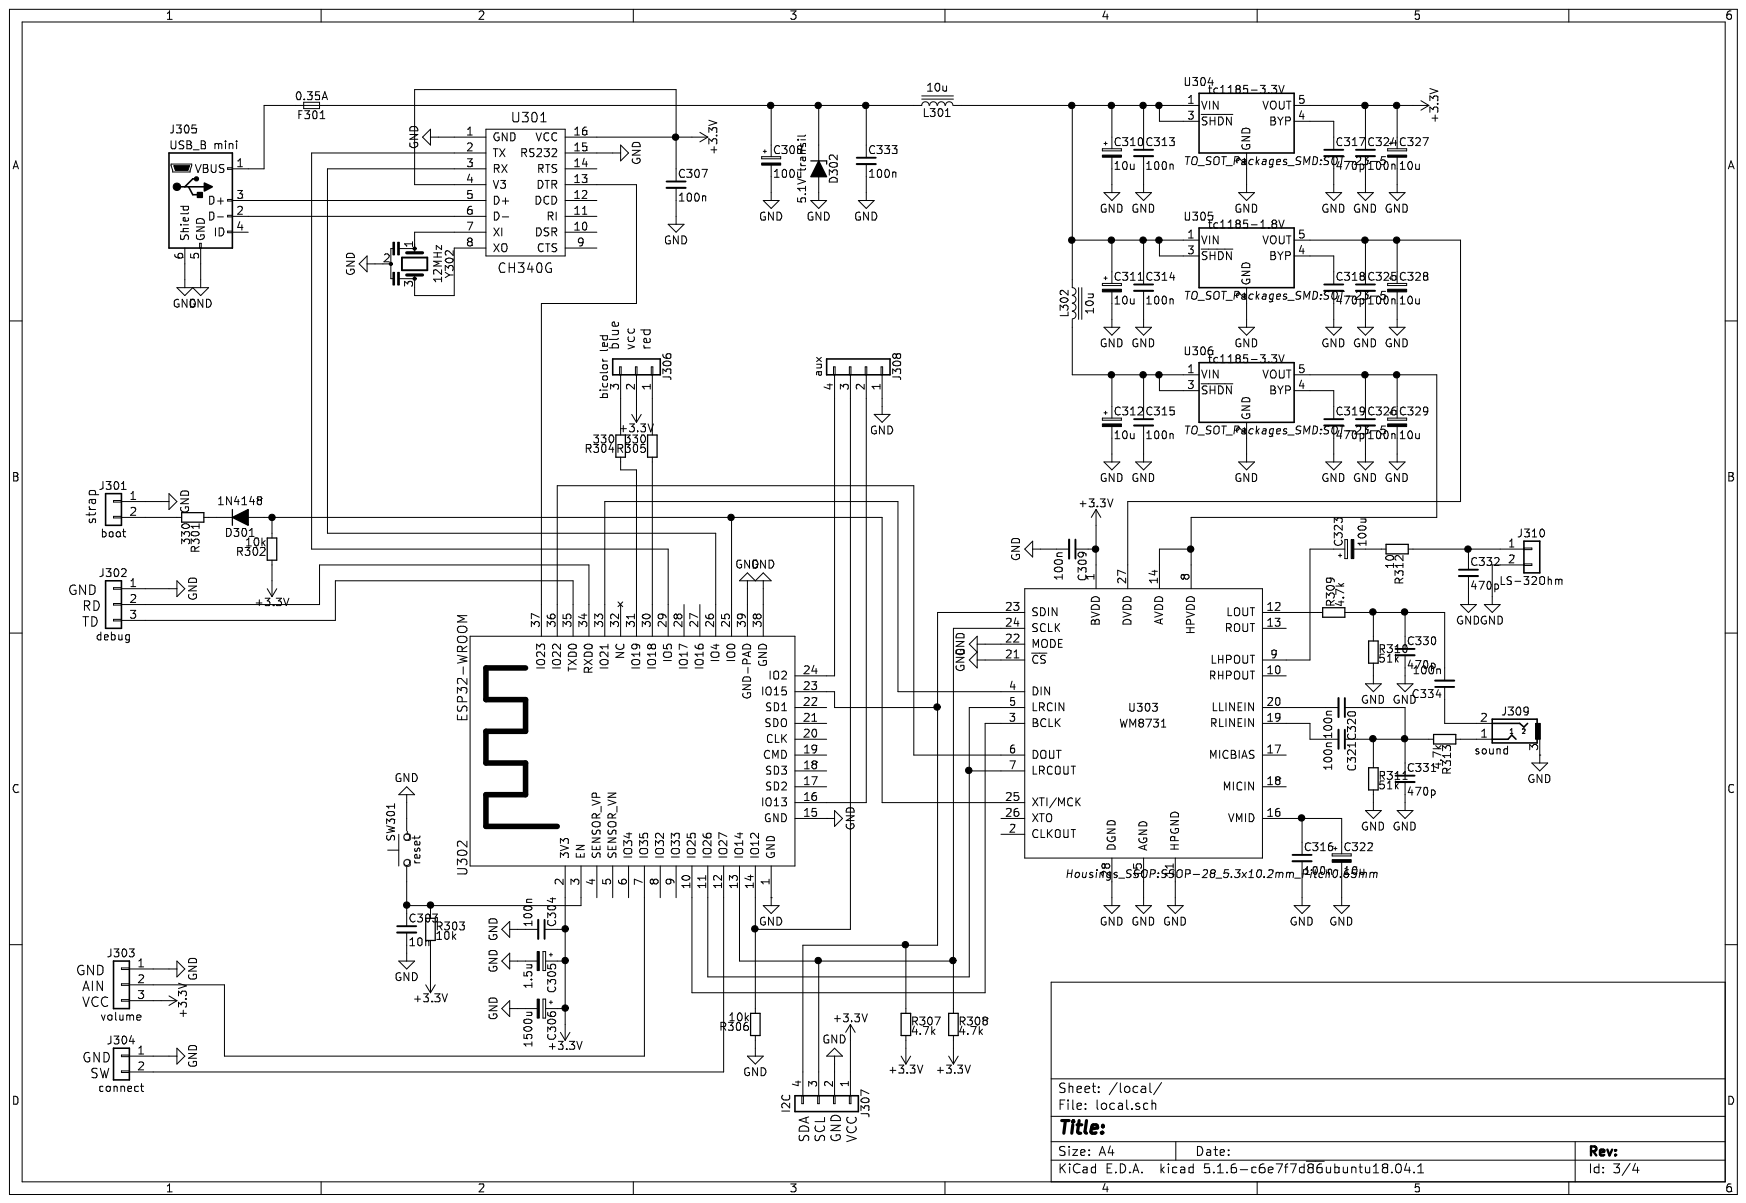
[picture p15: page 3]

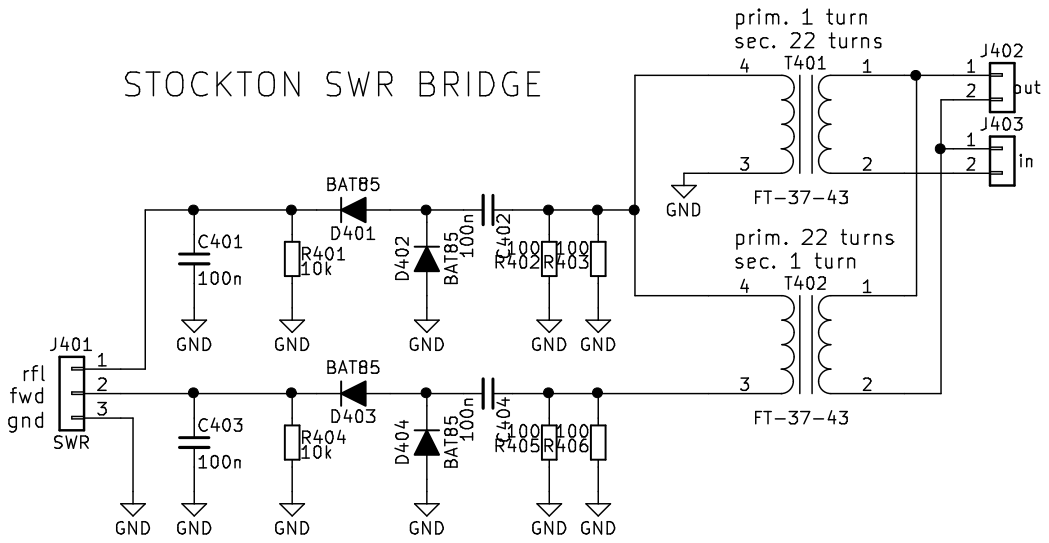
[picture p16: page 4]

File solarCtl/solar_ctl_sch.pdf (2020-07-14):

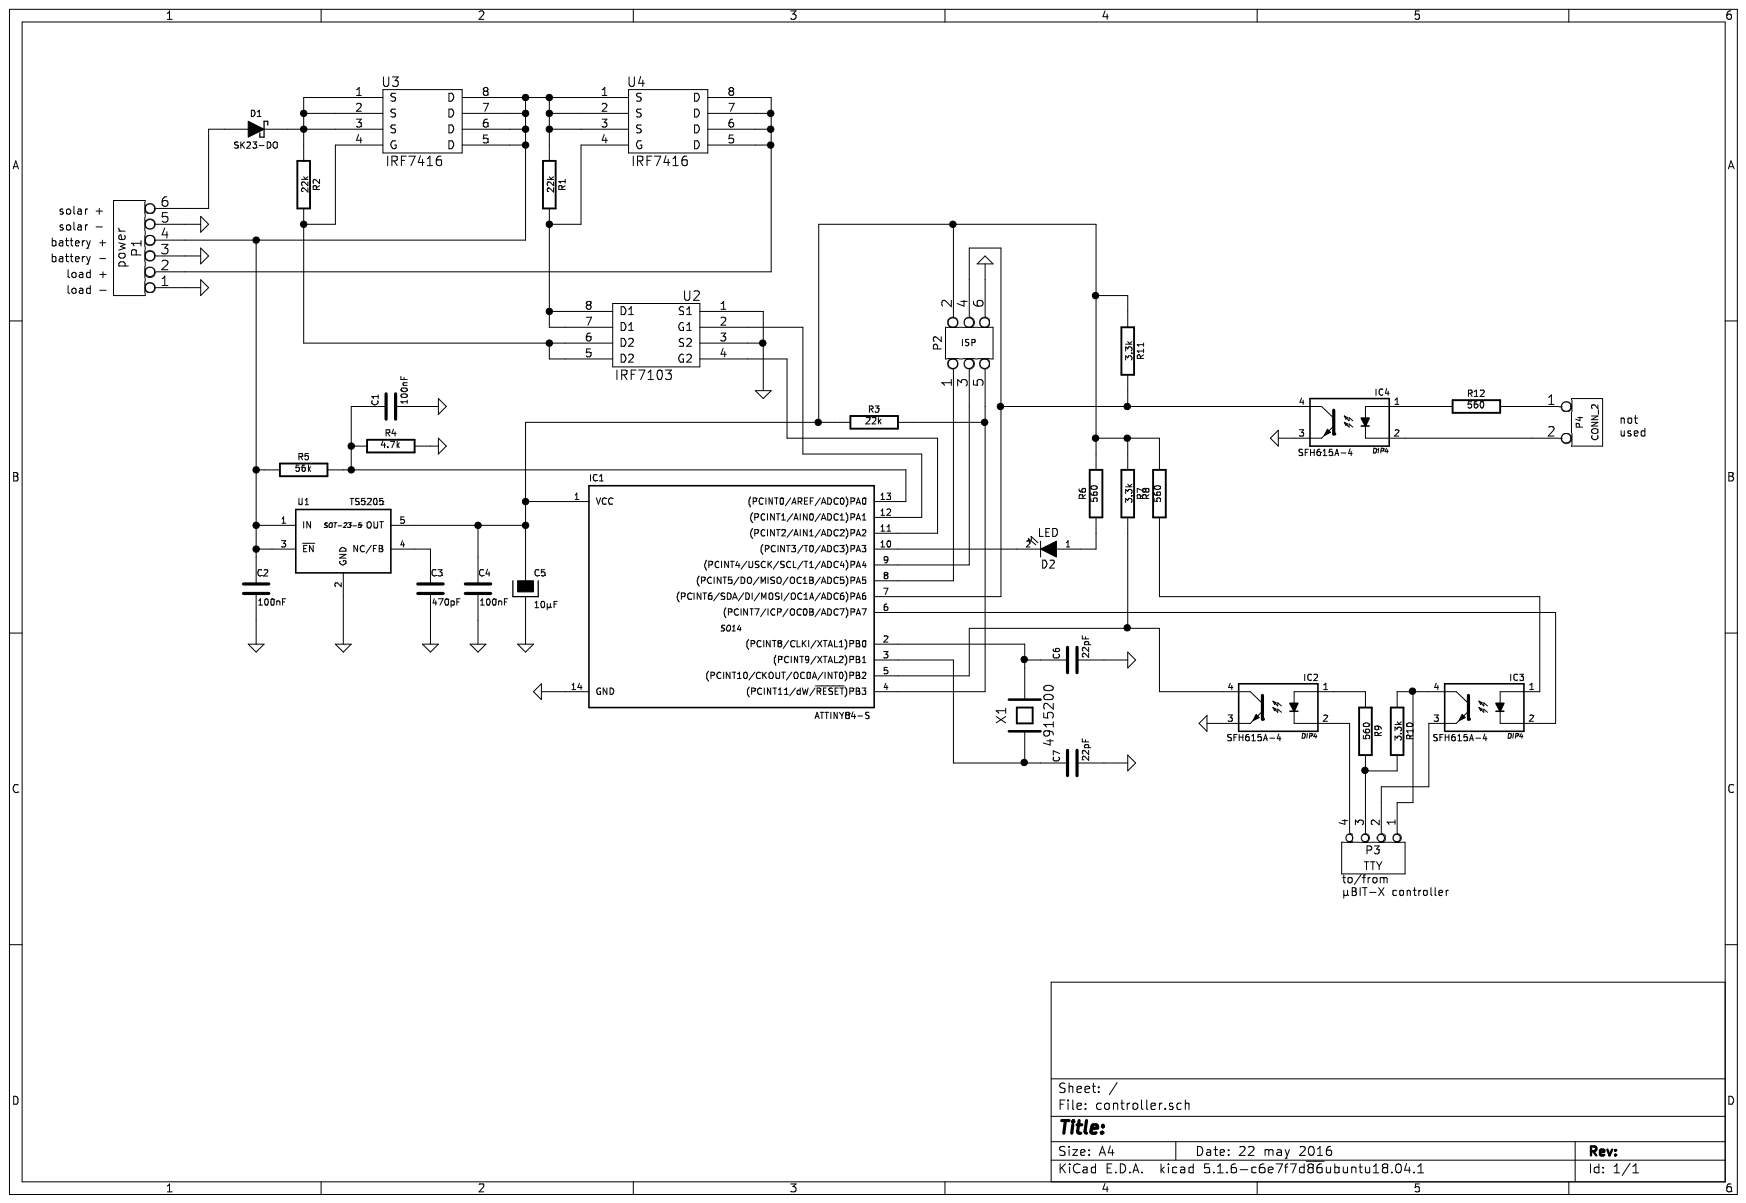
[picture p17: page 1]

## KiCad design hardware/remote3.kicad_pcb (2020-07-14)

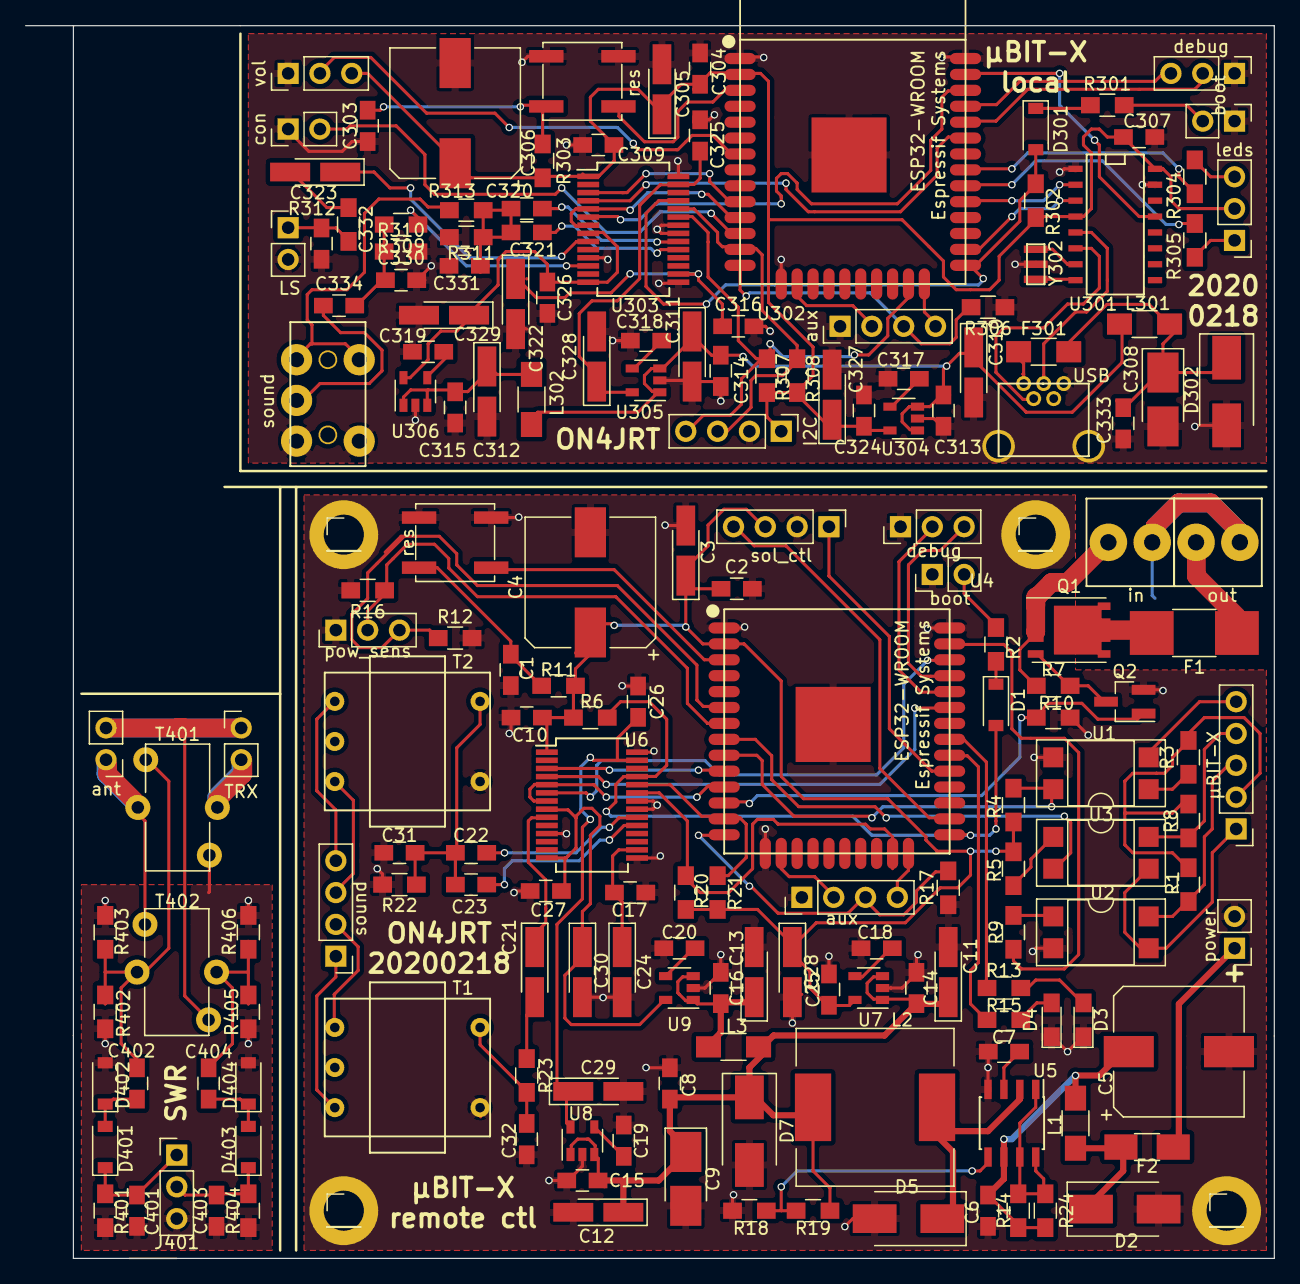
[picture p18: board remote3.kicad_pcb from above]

Board: 2 copper layers, 99.7 x 98.4 mm, 182 parts (0 on the bottom side), 123 nets.

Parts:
 : hole; Pin_Header_Straight_1x01_Pitch2.54mm
 #2,  #3,  #4: hole; Pin_Header_Straight_1x01_Pitch2.54mm
C1, C303: 10n; C_0805_HandSoldering
C2, C6, C8, C10, C14, C15, C16, C17, C22, C23, C25, C26, C27, C304, C307, C309, C313, C314, C315, C316, C320, C321, C324, C325, C326, C333, C334, C401, C402, C403, C404: 100n; C_0805_HandSoldering
C3, C305: 1.5u; CP_Tantalum_Case-A_EIA-3216-18_Hand
C4, C306: 1500u; CP_Elec_10x10
C5: 470u; CP_Elec_10x10
C7, C18, C19, C20, C31, C32, C317, C318, C319, C330, C331, C332: 470p; C_0805_HandSoldering
C9, C308: 100u; CP_Tantalum_Case-B_EIA-3528-21_Hand
C11, C12, C13, C21, C24, C28, C29, C30, C310, C311, C312, C322, C327, C328, C329: 10u; CP_Tantalum_Case-A_EIA-3216-18_Hand
C323: 100u; CP_Tantalum_Case-A_EIA-3216-18_Hand
D1, D301: 1N4148; D_SOD-123
D2: 15V transil; D_SMB_Handsoldering
D3: green; LED_0805_HandSoldering
D4: red; LED_0805_HandSoldering
D5: D_Schottky; D_SMB_Handsoldering
D7, D302: 5.1V transil; D_SMB_Handsoldering
D401, D402, D403, D404: BAT85; D_SOD-123
F1: 2.6A; R_1812_HandSoldering
F2: 0.35A; Fuse_SMD1206_HandSoldering
F301: 0.35A; R_1206_HandSoldering
I2C: I2C; Pin_Header_Straight_1x04_Pitch2.54mm
J401: SWR; Pin_Header_Straight_1x03_Pitch2.54mm
L1, L3, L301, L302: 10u; L_1206_HandSoldering
L2: 100u; L_12x12mm_h8mm
LS: LS-32Ohm; Pin_Header_Straight_1x02_Pitch2.54mm
Q1: AO4407A; PowerPAK_SO-8_Single
Q2: BSS138; SOT-23_Handsoldering
R1, R8, R20, R21, R307, R308, R309, R313: 4.7k; R_0805_HandSoldering
R2, R5, R9, R13, R15, R301, R304, R305: 330; R_0805_HandSoldering
R3: 680; R_0805_HandSoldering
R4: 3.3k; R_0805_HandSoldering
R6, R7, R10, R11, R17, R18, R302, R303, R306, R401, R404: 10k; R_0805_HandSoldering
R12, R16: 100k; R_0805_HandSoldering
R14, R24: 1; R_0805_HandSoldering
R19: 22k; R_0805_HandSoldering
R22, R310, R311: 51k; R_0805_HandSoldering
R23: 33; R_0805_HandSoldering
R312: 10; R_0805_HandSoldering
R402, R403, R405, R406: 100; R_0805_HandSoldering
T1, T2: 600Ohm 1/1; Transformer_NF_ETAL_1-1_P1200
T401, T402: FT-37-43; L_Toroid_Vertical_L10.0mm_W5.0mm_P5.08mm
TRX: in; Pin_Header_Straight_1x02_Pitch2.54mm
U1, U2, U3: LTV-817; DIP-4_W7.62mm_SMDSocket_SmallPads
U4, U302: ESP32-WROOM
U5: MC34063; SOIC-8_3.9x4.9mm_Pitch1.27mm
U6, U303: WM8731; SSOP-28_5.3x10.2mm_Pitch0.65mm
U7, U9, U304, U306: tc1185-3.3V; SOT-23-5
U8, U305: tc1185-1.8V; SOT-23-5
U301: CH340G; SO-16-N
USB: USB_B mini; USB_Micro-B_Wuerth-614105150721_Vertical_CircularHoles
Y302: 12MHz; Resonator_SMD-3pin_7.2x3.0mm
ant: out; Pin_Header_Straight_1x02_Pitch2.54mm
aux: aux; Pin_Header_Straight_1x04_Pitch2.54mm
aux#2: aux; Pin_Header_Straight_1x04_Pitch2.54mm
boot: boot; Pin_Header_Straight_1x02_Pitch2.54mm
boot#2: boot; Pin_Header_Straight_1x02_Pitch2.54mm
con: connect; Pin_Header_Straight_1x02_Pitch2.54mm
debug: debug; Pin_Header_Straight_1x03_Pitch2.54mm
debug#2: debug; Pin_Header_Straight_1x03_Pitch2.54mm
in: battery; TerminalBlock_bornier-2_P5.08mm
leds: bicolor led; Pin_Header_Straight_1x03_Pitch2.54mm
out: UBITX; TerminalBlock_bornier-2_P5.08mm
pow_sens: pw_sens; Pin_Header_Straight_1x03_Pitch2.54mm
power: power; Pin_Header_Straight_1x02_Pitch2.54mm
res: reset; SW_SPST_EVPBF
res#2: reset; SW_SPST_EVPBF
sol_ctl: solctl; Pin_Header_Straight_1x04_Pitch2.54mm
sound: sound; PJ320E_3.5mm_Jack
sound#2: sound; Pin_Header_Straight_1x04_Pitch2.54mm
vol: volume; Pin_Header_Straight_1x03_Pitch2.54mm
µBIT-X: CAT; Pin_Header_Straight_1x05_Pitch2.54mm

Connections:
+3V3: C2.1, C3.1, C4.1, C10.1, C25.1, C28.1, C304.1, C305.1, C306.1, C307.1, C309.1, C324.1, C327.1, I2C.1, R4.1, R5.1, R6.1, R11.2, R20.2, R21.2, R302.1, R303.2, R307.2, R308.2, U4.2, U6.1, U7.5, U301.4, U301.16, U302.2, U303.1, U304.5, leds.2, sol_ctl.3, vol.3
GND: .1, #2.1, #3.1, #4.1, C1.2, C2.2, C3.2, C4.2, C5.2, C6.2, C7.2, C8.2, C9.2, C10.2, C11.2, C12.2, C13.2, C14.2, C15.2, C16.2, C17.2, C18.2, C19.2, C20.2, C24.2, C25.2, C26.2, C27.2, C28.2, C29.2, C30.2, C31.2, C32.2, C303.2, C304.2, C305.2, C306.2, C307.2, C308.2, C309.2, C310.2, C311.2, C312.2, C313.2, C314.2, C315.2, C316.2, C317.2, C318.2, C319.2, C322.2, C324.2, C325.2, C326.2, C327.2, C328.2, C329.2, C330.2, C331.2, C332.2, C333.2, C401.2, C403.2, D2.2, D3.1, D4.1, D5.2, D7.2, D302.2, D402.2, D404.2, I2C.2, J401.3, LS.2, Q2.1, R10.2, R12.2, R16.2, R17.1, R18.2, R22.2, R306.1, R310.2, R311.2, R401.2, R402.1, R403.1, R404.2, R405.1, R406.1, T1.2, T2.2, T401.3, U1.3, U2.2, U4.1, U4.15, U4.38, U4.39, U5.4, U6.11, U6.15, U6.21, U6.22, U6.28, U7.2, U8.2, U9.2, U301.1, U301.15, U302.1, U302.15, U302.38, U302.39, U303.11, U303.15, U303.21, U303.22, U303.28, U304.2, U305.2, U306.2, USB.5, USB.6, Y302.2, aux.1, aux#2.1, boot.1, boot#2.1, con.1, debug.1, debug#2.1, in.2, out.2, pow_sens.1, power.2, res.2, res#2.2, sol_ctl.2, sound.3, vol.1
unnamed: C1.1, R11.1, U4.3, res.1
unnamed: C5.1, C6.1, L1.2, R14.2, R24.2, U5.6
unnamed: C7.1, U5.3
unnamed: C8.1, C9.1, C11.1, C12.1, C14.1, C15.1, D7.1, L2.2, L3.1, R19.2, U7.1, U7.3, U8.1, U8.3
unnamed: C13.1, C16.1, L3.2, U9.1, U9.3
unnamed: C17.1, C24.1, U6.16
unnamed: C18.1, U7.4
unnamed: C19.1, U8.4
unnamed: C20.1, U9.4
unnamed: C21.1, U6.9
unnamed: C21.2, R23.2
unnamed: C22.1, C23.1, C31.1, R22.1, T2.1
unnamed: C22.2, U6.20
unnamed: C23.2, U6.19
unnamed: C26.1, C29.1, U6.27, U8.5
unnamed: C27.1, C30.1, U6.8, U6.14, U9.5
unnamed: C32.1, R23.1, T1.1
unnamed: C303.1, R303.1, U302.3, res#2.1
unnamed: C308.1, C333.1, D302.1, F301.2, L301.1
unnamed: C310.1, C311.1, C313.1, C314.1, L301.2, L302.1, U304.1, U304.3, U305.1, U305.3
unnamed: C312.1, C315.1, L302.2, U306.1, U306.3
unnamed: C316.1, C322.1, U303.16
unnamed: C317.1, U304.4
unnamed: C318.1, U305.4
unnamed: C319.1, U306.4
unnamed: C320.1, C321.1, C331.1, R311.1, R313.2
unnamed: C320.2, U303.20
unnamed: C321.2, U303.19
unnamed: C323.1, U303.9
unnamed: C323.2, R312.2
unnamed: C325.1, C328.1, U303.27, U305.5
unnamed: C326.1, C329.1, U303.8, U303.14, U306.5
unnamed: C330.1, C334.2, R309.2, R310.1
unnamed: C332.1, LS.1, R312.1
unnamed: C334.1, sound.2
unnamed: C401.1, D401.1, J401.1, R401.1
unnamed: C402.1, R402.2, R403.2, T401.4, T402.4
unnamed: C402.2, D401.2, D402.1
unnamed: C403.1, D403.1, J401.2, R404.1
unnamed: C404.1, R405.2, R406.2, T402.3
unnamed: C404.2, D403.2, D404.1
unnamed: D1.1, R2.1
unnamed: D1.2, R6.2, U4.25, U6.25
unnamed: D2.1, F2.2, L1.1
unnamed: D3.2, R13.2
unnamed: D4.2, R15.2
unnamed: D5.1, L2.1, U5.2
unnamed: D301.1, R301.1
unnamed: D301.2, R302.2, U302.25, U303.25
unnamed: F1.1, out.1
unnamed: F1.2, Q1.2
unnamed: F2.1, power.1
unnamed: F301.1, USB.1
unnamed: Q1.1, R7.1, in.1
unnamed: U4.29, sol_ctl.1
unnamed: U4.26, sol_ctl.4
unnamed: U4.34, debug.2
unnamed: U4.35, debug.3
unnamed: R2.2, boot.2
unnamed: U2.3, U3.3, µBIT-X.1
unnamed: R1.1, R3.2, R8.2, µBIT-X.2
unnamed: R1.2, U2.4, µBIT-X.3
unnamed: R8.1, U3.4, µBIT-X.4
unnamed: U1.2, µBIT-X.5
unnamed: R16.1, U4.7, pow_sens.2
unnamed: R12.1, U4.6, pow_sens.3
unnamed: U4.16, aux#2.2
unnamed: R17.2, U4.14, aux#2.3
unnamed: U4.24, aux#2.4
unnamed: T1.4, sound#2.1
unnamed: T1.3, sound#2.2
unnamed: T2.4, sound#2.3
unnamed: T2.3, sound#2.4
unnamed: R301.2, boot#2.2
unnamed: U302.34, debug#2.2
unnamed: U302.35, debug#2.3
unnamed: U302.7, vol.2
unnamed: U302.12, con.2
unnamed: U301.6, USB.2
unnamed: U301.5, USB.3
unnamed: R305.2, leds.1
unnamed: R304.2, leds.3
unnamed: I2C.3, R308.1, U302.13, U303.24
unnamed: I2C.4, R307.1, U302.23, U303.23
unnamed: U302.16, aux.2
unnamed: R306.2, U302.14, aux.3
unnamed: U302.24, aux.4
unnamed: R313.1, sound.1
unnamed: T401.1, T402.1, ant.1
unnamed: T402.2, TRX.1, ant.2
unnamed: T401.2, TRX.2
unnamed: Q1.3, Q2.2, R7.2
unnamed: Q2.3, R10.1, U4.12
unnamed: R3.1, U1.1
unnamed: R4.2, U1.4, U4.9
unnamed: R5.2, U3.1
unnamed: R9.1, U2.1
unnamed: R9.2, U4.37
unnamed: R13.1, U4.31
unnamed: R14.1, R24.1, U5.1, U5.7, U5.8
unnamed: R15.1, U4.30
unnamed: R18.1, R19.1, U5.5
unnamed: R20.1, U4.23, U6.23
unnamed: R21.1, U4.13, U6.24
unnamed: R304.1, U302.31
unnamed: R305.1, U302.30
unnamed: R309.1, U303.12
unnamed: U3.2, U4.8
unnamed: U4.10, U6.3
unnamed: U4.11, U6.5, U6.7
unnamed: U4.33, U6.4
unnamed: U4.36, U6.6
unnamed: U301.2, U302.29
unnamed: U301.3, U302.26
unnamed: U301.7, Y302.1
unnamed: U301.8, Y302.3
unnamed: U301.13, U302.37
unnamed: U302.10, U303.3
unnamed: U302.11, U303.5, U303.7
unnamed: U302.33, U303.4
unnamed: U302.36, U303.6

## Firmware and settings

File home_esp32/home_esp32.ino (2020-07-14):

/* 
Audio and CAT transmission over the internet, 25 UDP packets/s
Home part of "Remote HF mk3" project
Uses a ESP32 WROOM module and a WM8731A codec, use "ESP32 Dev module" in the Arduino IDE
uses a small OLED graphic display, a small speaker and a few switches in parallel 
with a dedicated USB CAT interface.  Includes OTA, over the network softwate updates

Pin usage of ESP32 module:
 debug RD        pin 34 IO3
 debug TD        pin 35 IO1
 CAT TD          pin 29 IO5       should be high @ boot:  ok
 CAT RD          pin 26 IO4
 CAT PTT         pin 37 IO23
 freqa           pin 14 IO12      should be low/floating @ boot: ok
 I2C SCL         pin 13 IO14
 nc              pin 24 IO2       should be low/floating @ boot: ok
 I2C SDA         pin 23 IO15      should be high @ boot: ok
 I2S DIN         pin 33 IO21
 I2S DOUT        pin 36 IO22
 I2S FCLK        pin 11 IO26
 I2S BCLK        pin 10 IO25
 I2S MCLk        pin 25 IO0       should be low @ boot:  ok 
 grn led         pin 31 IO19
 red led         pin 30 IO18
 SWR-fwd         pin 7  IO35      ADC1-ch7, volume ctl
 connect         pin 12 IO26      switch
 freq0           pin 24 IO2       rotary encoder for frequency tuning
 freq1           pin 16 IO13
   
 Written by jean.taeymans@telenet.be
 01/03/20:  on the final hardware testing the various interfaces
 07/03/20:  running with remote, 
                -sound working in both directions
                -CAT working @2400 baud with µBIT-X emulator & with FLDIGI
                -CTL interface working, writing 8 system parameters on OLED
 11/03/20:  improved power indication, volume control on the LS output
              testing with a scheme to accerlerate the CAT, does not work well
              testing the PTT via the DTR f the USN, works ok, the serial port can still be used 
 15/03/20:  transparant CAT link to/ remote does not work with WSJT-X (long delays ?) 
              replaced by a simple terminal driven frequency & mode setting
              using a rotary encoder for fine frequency adjustment, to be improved    
 22/03/20:  2nd trial for a semi transparant CAT, works OK with FLdigi, does not work well with WSJT-X under Ubuntu   
 28/03/20:  final version, bug fixing & connection switch 
 31/03/20:  using small packets at 25 per s
 08/04/20:  some minor aesthetic fixing 
 20/04/20:  adding VOX capability, rationalise the several PTT methods  
 22/04/20:  adding the kill switch (turning the volume all the way down) 
 24/04/20:  correcting I2S bug, no rattle on the audio output anymore  
 20/05/20:  adding the AP fall back mode, no DNS lookup in case of direct WiFi connection to the remote 
 30/05/20:  not using EasyDDNS library, using traditional way, DDNS updates work ok now.  
*/

#include <Arduino.h>
#include "driver/i2s.h"
#include <Wire.h>
#include <WiFi.h>
#include <WiFiUdp.h>
#include "freertos/queue.h"
#include <WebServer.h>
#include <Update.h>
#include <HTTPClient.h>           // test
#include <WiFiMulti.h>            // multiple AP management
#include <Adafruit_GFX.h>         // drivers for the OLED display
#include "SSD1306.h"

// Pin definitions:
#define RD_u 5          // 2nd UART, USB CAT connection
#define TD_u 4    
#define PTT_u 23        // PTT input, DTR of USB CAT connection 
#define I2C_SDA 15      // I2C for WM8731 & OLED
#define I2C_SCL 14
#define I2S_DOUT 21     // I2S for WM8731
#define I2S_DIN 22
#define I2S_FCLK 26
#define I2S_BCLK 25
#define I2S_MCLK 0
#define vol_ctl 35      // analog input, LS volume control
#define con_sw 27       // connect switch
#define freq0 2         // rotary encoder for setting the frequency
#define freq1 13
#define freqa 12
#define G_LED 19        // debug leds
#define R_LED 18

#define oled 0x3c     // I2C address of OLED display
#define codec 0x1a    // I2C address of WM8731 codec

// other defines
#define SAMPLERATE 8000l

//i2s configuration 
int i2s_num = 0; // i2s port number
i2s_config_t i2s_config = {
     .mode = (i2s_mode_t)(I2S_MODE_MASTER | I2S_MODE_TX | I2S_MODE_RX),  
     .sample_rate = SAMPLERATE,
     .bits_per_sample = I2S_BITS_PER_SAMPLE_16BIT,
     .channel_format = I2S_CHANNEL_FMT_RIGHT_LEFT,
     .communication_format = (i2s_comm_format_t)(I2S_COMM_FORMAT_I2S | I2S_COMM_FORMAT_I2S_LSB),
     .intr_alloc_flags = ESP_INTR_FLAG_LEVEL1, // high interrupt priority, interrupt level 1
     .dma_buf_count = 8,
     .dma_buf_len = 256, 
     .use_apll = true
  };
i2s_pin_config_t pin_config = {
    .bck_io_num = I2S_BCLK, 
    .ws_io_num = I2S_FCLK, 
    .data_out_num = I2S_DOUT, 
    .data_in_num = I2S_DIN  
  };

// Network stuff
const char home_name[] = "home.duckdns.org";      // example, to be adapted according the network
const char remote_name[] = "remote.duckdns.org";  // example, to be adapted according the network
const int udp_h_port = 1234; // port for data transfer to the home device
const int udp_r_port = 1235; // port for data transfer to the remote device
const int tcp_u_port = 1236; // port for OTA updates

// Set gateway and static IP addresses  
IPAddress IP_home(192, 168, 0, 207);       // example, to be adapted according the network
IPAddress IP_remote(192, 168, 0, 208);     // example, to be adapted according the network
IPAddress gateway(192, 168, 0, 1);         // example, to be adapted according the network
IPAddress subnet(255, 255, 255, 0);        // example, to be adapted according the network
IPAddress primaryDNS(123, 123, 123, 123);  // example, to be adapted according the network
IPAddress secondaryDNS(123, 123, 123, 123);// example, to be adapted according the network

// DynDNS client
HTTPClient duckreq;

// OLED 
SSD1306  display(oled, I2C_SDA, I2C_SCL);

// Data structure for access point manager
WiFiMulti wifiMulti;

// define the UDP server, at first for the NTP
WiFiUDP udp;

// OTA update server, need a pin hole for port 1236/tcp through the router
WebServer server(tcp_u_port);       
// Login page 
const char* loginIndex = 
 "<form name='loginForm'>"
    "<table width='20%' bgcolor='A09F9F' align='center'>"
        "<tr>"
            "<td colspan=2>"
                "<center><font size=4><b>ESP32 Login Page</b></font></center>"
                "<br>"
            "</td>"
            "<br>"
            "<br>"
        "</tr>"
        "<td>Username:</td>"
        "<td><input type='text' size=25 name='userid'><br></td>"
        "</tr>"
        "<br>"
        "<br>"
        "<tr>"
            "<td>Password:</td>"
            "<td><input type='Password' size=25 name='pwd'><br></td>"
            "<br>"
            "<br>"
        "</tr>"
        "<tr>"
            "<td><input type='submit' onclick='check(this.form)' value='Login'></td>"
        "</tr>"
    "</table>"
"</form>"
"<script>"
    "function check(form)"
    "{"
    "if(form.userid.value=='on4jrt' && form.pwd.value=='123456789')"
    "{"
    "window.open('/serverIndex')"
    "}"
    "else"
    "{"
    " alert('Error Password or Username') /*displays error message*/"
    "}"
    "}"
"</script>";

// Server Index Page 
const char* serverIndex = 
"<script src='https://ajax.googleapis.com/ajax/libs/jquery/3.2.1/jquery.min.js'></script>"
"<form method='POST' action='#' enctype='multipart/form-data' id='upload_form'>"
   "<input type='file' name='update'>"
        "<input type='submit' value='Update'>"
    "</form>"
 "<div id='prg'>progress: 0%</div>"
 "<script>"
  "$('form').submit(function(e){"
  "e.preventDefault();"
  "var form = $('#upload_form')[0];"
  "var data = new FormData(form);"
  " $.ajax({"
  "url: '/update',"
  "type: 'POST',"
  "data: data,"
  "contentType: false,"
  "processData:false,"
  "xhr: function() {"
  "var xhr = new window.XMLHttpRequest();"
  "xhr.upload.addEventListener('progress', function(evt) {"
  "if (evt.lengthComputable) {"
  "var per = evt.loaded / evt.total;"
  "$('#prg').html('progress: ' + Math.round(per*100) + '%');"
  "}"
  "}, false);"
  "return xhr;"
  "},"
  "success:function(d, s) {"
  "console.log('success!')" 
 "},"
 "error: function (a, b, c) {"
 "}"
 "});"
 "});"
 "</script>";

// global variables
#define snd_buf_size 8000l    // output buffer 1s mono
#define in_bufs 2
#define in_buf_size 320       // 25 small packets per s
#define udp_buf_size 660      // = (snd_buf_size * 2) + 20
#define udp_pac_cnt 640
#define udp_ctl_cnt 641
#define udp_cat_mes 642       // start of cat message, max 5 bytes
#define udp_ctl_mes 647       // start of ctl message, max 13 bytes

#define voxThreshold 10000    // amplitude threshold (absolute value) of VOX trigger, about 0.35Veff

int16_t snd_buf[snd_buf_size];
uint16_t in_buf[in_bufs][in_buf_size];   // input data buffer, buffering two times 0.08s of sound, i.e. twice 640 samples/1280 bytes
uint16_t current_in_buf = 0;             // which data buffer is being used for input and which is being used for output
uint16_t current_out_buf = 0;
uint16_t in_buf_pos = 0;                 // position in the input data buffer, will advance 2 each sample
int16_t silence[2] = { 0, 0};
int16_t temp[2] = { 0, 0};
int16_t synth[2] = { 0, 0};
int16_t snd_buf_w = 0, snd_buf_r = 0;
int16_t in_buf_w = 0, in_buf_r = 0;
int32_t snd_buf_fill;
int32_t in_buf_fill;
boolean snd_on = false, wifi_on = false;
char tmpstr[32], tmpstrs[16];
uint8_t udp_r_buf[udp_buf_size];
uint8_t udp_s_buf[udp_buf_size];
uint16_t rx_pac_cnt = 0, tx_pac_cnt = 0, pac_num = 0, exp_pac_num = 0;
char *pos;
float bat_volt, fpow_fwd, fpow_rfl, rfl_coef, swr;
int16_t temp_rem, pow_fwd, pow_rfl, rem_pac, rssi_rem;
uint8_t vol = 121, old_vol = 121;
uint16_t pot_val = 60558;
boolean ptt_cat = false, ptt_rf = false, ptt_hf = false, ptt_hf_old = false, ptt_tim = false;
boolean ptt_cat_old = false, ptt_dtr_old = false, ptt_vox_old = false, con_sw_old = false;
boolean kill_fl = false;
int16_t vox = 0;
long ptt_time = 0;
#define max_ptt 180000l         // max transmission time, 3min

uint8_t cat_in[5], cat_out[5];
uint8_t cat_mode = 0x01, old_cat_mode = 0x01;
long freq = 14074000l, old_freq = 14074000l, displ_freq;
boolean cat_in_fl = false, cat_out_fl = false, extra_ctl = false;
int16_t puls = 0;

boolean splitActive = false;
boolean vfoAActive = true;
boolean cat_enabled = true;   
byte nullPad[5] = {0,0,0,0,0};
uint16_t cat_cnt, ctl_cnt;

uint16_t accu = 0, adder = 0;

const uint8_t wm8731_regs[12][2] = {  // WM8731 initialization
  { 0x1e, 0x00 },   //  reset
  { 0x0c, 0x10 },   //  power control: all on except output
  { 0x0e, 0x01 },   //  data format: slave mode, 16bit, MSB-First, left justified
  { 0x00, 0x17 },   //  lin vol: 0dB
  { 0x02, 0x17 },   //  rin vol: 0dB
  { 0x04, 0x79 },   //  lhp vol: 0dB
  { 0x06, 0x79 },   //  rhp vol: 0dB
  { 0x08, 0x10 },   //  ana conf: DAC select & line in select
  { 0x0a, 0x00 },   //  dig conf: normal
  { 0x10, 0x00 },   //  sample rate: normal, 48ks/s @ 12288kHz MCLK yields 8ks/s @ 2048kHz
  { 0x12, 0x01 },   //  enable: interface active
  { 0x0c, 0x00 } }; //  power control, all on incl. output

const int16_t sine[256] = { 0, 245, 491, 736, 980, 1224, 1467, 1710, 1951, 2191, 2430, 2667, 2903, 3137, 3369, 3599, 3827, 4052, 4276,
                          4496, 4714, 4929, 5141, 5350, 5556, 5758, 5957, 6152, 6344, 6532, 6716, 6895, 7071, 7242, 7410, 7572, 7730,
                          7883, 8032, 8176, 8315, 8449, 8577, 8701, 8819, 8932, 9040, 9142, 9239, 9330, 9415, 9495, 9569, 9638, 9700,
                          9757, 9808, 9853, 9892, 9925, 9952, 9973, 9988, 9997, 10000, 9997, 9988, 9973, 9952, 9925, 9892, 9853, 9808,
                          9757, 9700, 9638, 9569, 9495, 9415, 9330, 9239, 9142, 9040, 8932, 8819, 8701, 8577, 8449, 8315, 8176, 8032,
                          7883, 7730, 7572, 7410, 7242, 7071, 6895, 6716, 6532, 6344, 6152, 5957, 5758, 5556, 5350, 5141, 4929, 4714,
                          4496, 4276, 4052, 3827, 3599, 3369, 3137, 2903, 2667, 2430, 2191, 1951, 1710, 1467, 1224, 980, 736, 491, 245,
                          0, -245, -491, -736, -980, -1224, -1467, -1710, -1951, -2191, -2430, -2667, -2903, -3137, -3369, -3599, -3827, -4052, -4276,
                          -4496, -4714, -4929, -5141, -5350, -5556, -5758, -5957, -6152, -6344, -6532, -6716, -6895, -7071, -7242, -7410, -7572, -7730,
                          -7883, -8032, -8176, -8315, -8449, -8577, -8701, -8819, -8932, -9040, -9142, -9239, -9330, -9415, -9495, -9569, -9638, -9700,
                          -9757, -9808, -9853, -9892, -9925, -9952, -9973, -9988, -9997, -10000, -9997, -9988, -9973, -9952, -9925, -9892, -9853, -9808,
                          -9757, -9700, -9638, -9569, -9495, -9415, -9330, -9239, -9142, -9040, -8932, -8819, -8701, -8577, -8449, -8315, -8176, -8032,
                          -7883, -7730, -7572, -7410, -7242, -7071, -6895, -6716, -6532, -6344, -6152, -5957, -5758, -5556, -5350, -5141, -4929, -4714,
                          -4496, -4276, -4052, -3827, -3599, -3369, -3137, -2903, -2667, -2430, -2191, -1951, -1710, -1467, -1224, -980, -736, -491, -245 };

const uint8_t message[] = {  // "THE QUICK BROWN FOX JUMPS OVER THE LAZY DOG 0123456789 !"
                          0x08, 0x02, 0x1f, 0x1f, 0x10, 0x14, 0x01, 0x04, 0x17, 0x07, 0x06, 0x0e, 0x0f, 0x04, 0x19, 0x0a, 
                          0x18, 0x13, 0x0c, 0x04, 0x0d, 0x18, 0x1d, 0x04, 0x0b, 0x07, 0x1c, 0x16, 0x05, 0x04, 0x18, 0x1e, 
                          0x01, 0x0a, 0x04, 0x10, 0x14, 0x01, 0x04, 0x12, 0x03, 0x11, 0x15, 0x04, 0x09, 0x18, 0x1a, 0x04,
                          0x04, 0x04, 0x1b, 0x1b, 0x16, 0x17, 0x13, 0x01, 0x0a, 0x10, 0x15, 0x07, 0x06, 0x18, 0x04, 0x1b, 0x0d };


// *********************************************************************************************
// *  ISR function, used for the rotary encoder                                                                         *
// *********************************************************************************************
// for some reason this has to be located in RAM, beware, calls to non RAM located functions are not allowed
void ICACHE_RAM_ATTR rotary(void)
{  // we come here only at falling edge of freq0
  if(digitalRead(freq1)) puls++;
  else puls--;
}
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
void loop() {
  uint16_t i, j;
// structure of a packet, 660 bytes in total:
  // bytes 0...639 :    320 16bit sound samples, 8000 samples/s
  // byte 640 :         packet count [0...255]
  // byte 641 :         bits 7...4: number of CTL bytes [0...13], bit 3: echo of PTT state, bits 0...2: number of CAT bytes [0...5], 
  // byte 642...646 :   CAT bytes, max 5
  // byte 647...659 :   CTL bytes, max 13
  
//  ************************* handling an incoming UDP packet  ********************************
 // if there's data available, read a packet
  int packetSize = udp.parsePacket();
  if (packetSize == udp_buf_size) {
    udp.read(udp_r_buf, udp_buf_size);
    rx_pac_cnt++;     // increment the received packet count
    
    // handle sound part
    for (i = 0; i < in_buf_size; i++) {  
      // transform the first 1280/640 bytes into 640/320 sound samples 
      snd_buf[snd_buf_w] = (uint16_t)udp_r_buf[i * 2] << 8;
      snd_buf[snd_buf_w] += (uint16_t)udp_r_buf[(i * 2) + 1];
      snd_buf_w++;       
      if (snd_buf_w == snd_buf_size) snd_buf_w = 0; 
    }   

    // decode the control bytes @ positions 1280 & 1281 or 640 & 641
    pac_num = (uint16_t)udp_r_buf[udp_pac_cnt];
    if (exp_pac_num != pac_num) Serial.println("!");      // debugging, print "!" when not expected packet #
    exp_pac_num = pac_num + 1;
    if (exp_pac_num > 255) exp_pac_num = 0;
    ctl_cnt = (uint16_t)(udp_r_buf[udp_ctl_cnt] >> 4);
    if ((udp_r_buf[udp_ctl_cnt] & 0x08) == 0x08) ptt_rf = true;
    else ptt_rf = false;
    cat_cnt = (uint16_t)(udp_r_buf[udp_ctl_cnt] & 0x07);
    
    digitalWrite(G_LED, !digitalRead(G_LED));

    // handle the CAT part     
    if (cat_cnt == 5) {                       // display frequency & status response
      displ_freq = readFreq(&udp_r_buf[udp_cat_mes]);
      uint16_t displ_M = displ_freq / 1000000;
      uint16_t displ_k = (displ_freq % 1000000) / 1000;
      uint16_t displ_u = displ_freq % 1000;
      if (ptt_rf == true) {
        if (udp_r_buf[udp_cat_mes + 4] == 0x01) sprintf(tmpstrs, "%2d.%03d.%03dHz U", displ_M, displ_k, displ_u);
        else sprintf(tmpstrs, "%2d.%03d.%03dHz L", displ_M, displ_k, displ_u);
      } else {
        if (udp_r_buf[udp_cat_mes + 4] == 0x01) sprintf(tmpstrs, "%2d.%03d.%03dHz u", displ_M, displ_k, displ_u);
        else sprintf(tmpstrs, "%2d.%03d.%03dHz l", displ_M, displ_k, displ_u);
      }      
      display.setColor(BLACK);
      display.fillRect(0, 0, 128, 16);          // line 1
      display.setColor(WHITE);   
      display.setFont(ArialMT_Plain_16);
      display.drawString(0, 0, tmpstrs);
      display.display();    
    }
    /*
    // play with leds during receiving
    if ((digitalRead(PTT_u)) && (ptt_fl == false)) {        // receiving
      digitalWrite(G_LED, !digitalRead(G_LED));
      digitalWrite (R_LED, HIGH);
    } else {                                               // transmitting
      digitalWrite (R_LED, !digitalRead(R_LED));
      digitalWrite (G_LED, HIGH);
    }  
    */
    // handle the ctl part
    if (ctl_cnt != 0) {
      for (j = 0; j < ctl_cnt; j++) tmpstr[j] = udp_r_buf[udp_ctl_mes + j];
      tmpstr[ctl_cnt] = 0;
      extra_ctl = false;
             
      pos = strstr(tmpstr, "B=");                  // battery voltage and temperature
      if ( pos != NULL) {
        pos += 2;
        bat_volt = (float)atoi(pos) / 1000.;
        pos = strstr(tmpstr, "T=");	
        if ( pos != NULL) {       // pos == NULL is still possible, if message was broken
          pos += 2;
          temp_rem = atoi(pos);
          sprintf(tmpstrs, "%6.3fV    %d'C", bat_volt, temp_rem);
          display.setColor(BLACK);
          display.fillRect(0, 48, 128, 16);           // line 4 (bottom)
          display.setColor(WHITE);   
          display.setFont(ArialMT_Plain_16);
          display.drawString(0, 48, tmpstrs);
          display.display(); 
          extra_ctl = true;
        }
      }  

      pos = strstr(tmpstr, "Y=");                   // WiFi RSSI value
      if ( pos != NULL) { 
        extra_ctl = true; 
        if (ptt_rf == false) {                      // only while receiving  
          pos += 2;  
          rssi_rem = atoi(pos);
          sprintf(tmpstrs, "%ddBm   %ddBm", rssi_rem, (int)WiFi.RSSI());
          display.setColor(BLACK);
          display.fillRect(0, 32, 128, 16);         // line 3
          display.setColor(WHITE);   
          display.setFont(ArialMT_Plain_16);
          display.drawString(0, 32, tmpstrs);
          display.display();
        }     
      }
                                               
      pos = strstr(tmpstr, "P=");                 // forward and reflected power
      if ( pos != NULL) {  
        extra_ctl = true;
        if (ptt_rf == true) {                     // only while transmitting  
          pos += 2;  
          pow_fwd = atoi(pos);
          pos = strstr(tmpstr, "/");
          pos += 1;
          pow_rfl = atoi(pos);
        // Using ADC of remote: 12bit, 4095 adcnts = 3.2Vp (detected) or 1.13Vrms HF
        // using 1/22 current ratio this equates to 0.5Arms in 50Ohm or 12.5W 
          fpow_fwd = ((float)pow_fwd) / 82.73;   // calibrated
          fpow_rfl = ((float)pow_rfl) / 82.73;   // calibrated
          fpow_fwd = fpow_fwd * fpow_fwd / 50.0;
          fpow_rfl = fpow_rfl * fpow_rfl / 50.0;
          if (fpow_fwd > 1.0) {
            rfl_coef = fpow_rfl / fpow_fwd;
            if (rfl_coef > 0.81 ) rfl_coef = 0.81;  // limit SWR indication to ca. 10.0
            swr = (1 + rfl_coef) / (1 - rfl_coef);
          } else {
            swr = 1.0;   
          }
          sprintf(tmpstrs, "%4.1fW    %3.1fSWR", fpow_fwd, swr);
          display.setColor(BLACK);
          display.fillRect(0, 32, 128, 16);        // line 3 
          display.setColor(WHITE);   
          display.setFont(ArialMT_Plain_16);
          display.drawString(0, 32, tmpstrs);
          display.display();
        }
      }
      // display received packet count: home -> remote
      pos = strstr(tmpstr, "Z=");        
      if ( pos != NULL) {   
        pos += 2;  
        rem_pac = atoi(pos);
        sprintf(tmpstrs, "%d/K", rem_pac);
        display.setColor(BLACK);
        display.fillRect(0, 16, 64, 16);          // line 2, left part
        display.setColor(WHITE);   
        display.setFont(ArialMT_Plain_16);
        display.drawString(0, 16, tmpstrs);
        display.display();
        extra_ctl = true;
      }
      // detect the response of a kill request
      pos = strstr(tmpstr, "Bye");        
      if ( pos != NULL) {   
        sprintf(tmpstrs, "   Bye Bye");
        display.setColor(BLACK);
        display.fillRect(0, 0, 128, 16);          // line 1
        display.setColor(WHITE);   
        display.setFont(ArialMT_Plain_16);
        display.drawString(0, 0, tmpstrs);
        display.display();
        extra_ctl = true;
      }
      // if nothing has been parsed in a non-empty ctl message, just print it
      if (!extra_ctl) Serial.println(tmpstr);
    } 
  }
  delay(1);
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

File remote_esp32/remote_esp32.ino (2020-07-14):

/*
  Audio and CAT transmission over the internet, 25 UDP packets/s in both directions
  The controller part of the "Remote HF mk3" project, wich includes a µBIT-X transceiver
  Uses a ESP32 WROOM module and a WM8731A codec, use "ESP32 Dev module" in the Arduino IDE
  Includes OTA, over the network software updates
  - connected to the µBIT-X with an isolated serial port, Rd, TD & PTT, emulating the CAT interface
  - connected to the µBIT-X with an isolated audio interface, receive and transmit
  - connected to the solar controller module for timing and battery supervision
  The Remote HF mk3 will attempt to connect to the strongest of a small number of APs when in range,
  failing that it will be become in itself an AP for local connection to the home device
  
  Pin usage of ESP32 module:
  debug RD        pin 34 IO3
  debug TD        pin 35 IO1
  Solar RD        pin 29 IO5       should be high @ boot: ok
  Solar TD        pin 26 IO4
  µBIT-X RD       pin 9  IO33
  µBIT-X TD       pin 8  IO32
  µBIT-X PTT      pin 37 IO23
  nc              pin 14 IO12      should be low/floating @ boot: ok
  I2C SCL         pin 13 IO14
  nc              pin 24 IO2       should be low/floating @ boot: ok
  I2C SDA         pin 23 IO15      should be high @ boot: ok
  I2S DOUT        pin 33 IO21
  I2S DIN         pin 36 IO22
  I2S FCLK        pin 11 IO26
  I2S BCLK        pin 10 IO25
  I2S MCLk        pin 25 IO0       should be low @ boot:  ok
  BITX-on         pin 12 IO27
  grn led         pin 31 IO19
  red led         pin 30 IO18
  SWR-fwd         pin 7  IO35      ADC1-ch7
  SWR-rev         pin 6  IO34      ADC1-ch6
  debug           pin    IO13      not used

  Written by jean.taeymans@telenet.be
  05/02/20:   working on the development hardware, audio loopback through a 5s buffer
              issues: - does not boot well, need to decouple the hardware
                      - WM8731 does not work with the regular I2C; need the bit banged version
                      - does not work when using IO12/IO14 for the I2C, TBC
  14/02/20:   still on the development hardware, same functionality, including OTA updates
              problems with booting and with I2C solved, WM8731 works with regular Wire library
              must use IO14/IO15 for the I2C
  16/02/20:   still on the development hardware, including interaction with solar controller
              and mail sending client
  28/02/20:   on the final hardware testing the various interfaces
  07/03/20:   running with remote,
              -sound working in both directions
              -CAT working @2400 baud with µBIT-X emulator & with FLDIGI
              -CTL interface working, writing 8 system parameters on OLED
  11/03/20:   improved power indication, volume control on the LS output
              fully transparant CAT does not work very well @ 4800 baud, due to transmission delays
  31/03/20:   final version, including conditional transmission and the use of 25 small packets per s
  08/04/20:   some minor aesthetic fixings  
  22/04/20:   again some minor fixings related to stand alone mode, small delay on the PTT
  24/04/20:   correcting I2S bug, no rattle on the audio out anymore
  20/05/20:   adding the fall back to AP mode, when no real APs are in range
  15/06/20:   not using EasyDDNS library, using traditional way, DDNS updates work ok now.  
*/

#include <Arduino.h>
#include "driver/i2s.h"
#include <Wire.h>
#include <WiFi.h>
#include <WiFiUdp.h>
#include <NTPClient.h>            // F. Weinberg 3.1, NTP client
#include "freertos/queue.h"
#include <WebServer.h>
#include <Update.h>
#include "ESP32_MailClient.h"     // Mobizt, 2.1.4, mail client for sending
#include <WiFiMulti.h>            // multiple AP management, take the strongest available

// Pin definitions:
#define RD_s 5          // 3rd UART, connection with the Solar/Battery controller
#define TD_s 4
#define RD_u 33         // 2nd UART, CAT connection with µBIT-X
#define TD_u 32
#define PTT_u 23        // PTT output to µBIT-X
#define BITX_u 27       // power switch for µBIT-X
#define I2C_SDA 15      // I2C for WM8731
#define I2C_SCL 14
#define I2S_DOUT 21     // I2S for WM8731
#define I2S_DIN 22
#define I2S_FCLK 26
#define I2S_BCLK 25
#define I2S_MCLK 0
#define SWR_fwd 35      // analog inputs for SWR bridge 
#define SWR_rfl 34
#define G_LED 18        // debug leds
#define R_LED 19
#define DEBUG 13        // debug mode, no used for now

// other defines
#define SAMPLERATE 8000l
#define codec 0x1a    // I2C address of WM8731 codec

//i2s configuration
int i2s_num = 0;           // i2s port number
i2s_config_t i2s_config = {
  .mode = (i2s_mode_t)(I2S_MODE_MASTER | I2S_MODE_TX | I2S_MODE_RX),
  .sample_rate = SAMPLERATE,
  .bits_per_sample = I2S_BITS_PER_SAMPLE_16BIT,
  .channel_format = I2S_CHANNEL_FMT_RIGHT_LEFT,
  .communication_format = (i2s_comm_format_t)(I2S_COMM_FORMAT_I2S | I2S_COMM_FORMAT_I2S_LSB),
  .intr_alloc_flags = ESP_INTR_FLAG_LEVEL1, // high interrupt priority, interrupt level 1
  .dma_buf_count = 8,
  .dma_buf_len = 256,
  .use_apll = true
};
i2s_pin_config_t pin_config = {
  .bck_io_num = I2S_BCLK,
  .ws_io_num = I2S_FCLK,
  .data_out_num = I2S_DOUT,
  .data_in_num = I2S_DIN
};

// Network stuff
const char home_name[] = "home.duckdns.org";              // to be adapted according to own configuration
const char remote_name[] = "remote.duckdns.org";          // to be adapted according to own configuration
const char AP_ssid[] = "RemoteHF";                        // in case no friendly AP is present
const char AP_password[] = "123456789";
const int udp_h_port = 1234; // port for data transfer to the home device
const int udp_r_port = 1235; // port for data transfer to the remote device
const int tcp_u_port = 1236; // port for OTA updates

// Set gateway and static IP addresses  
IPAddress IP_home(192, 168, 1, 207);        // example, to be adapted according to own configuration
IPAddress IP_remote(192, 168, 1, 208);      // example, to be adapted according to own configuration
IPAddress gateway(192, 168, 1, 1);          // example, to be adapted according to own configuration
IPAddress subnet(255, 255, 255, 0);         // example, to be adapted according to own configuration
IPAddress primaryDNS(123, 123, 123, 123);    // example, to be adapted according to own configuration
IPAddress secondaryDNS(123, 123, 123, 123); // example, to be adapted according to own configuration

// Define NTP Client to get the network time
WiFiUDP ntpUDP;
NTPClient timeClient(ntpUDP);
// Variables to save date and time
String formattedDate;
String dayStamp;
String timeStamp;

// DynDNS client
HTTPClient duckreq;

// Data structure for access point manager
WiFiMulti wifiMulti;

// define the UDP server
WiFiUDP udp;

// The Email Sending data object contains config and data to send
SMTPData smtpData;
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
